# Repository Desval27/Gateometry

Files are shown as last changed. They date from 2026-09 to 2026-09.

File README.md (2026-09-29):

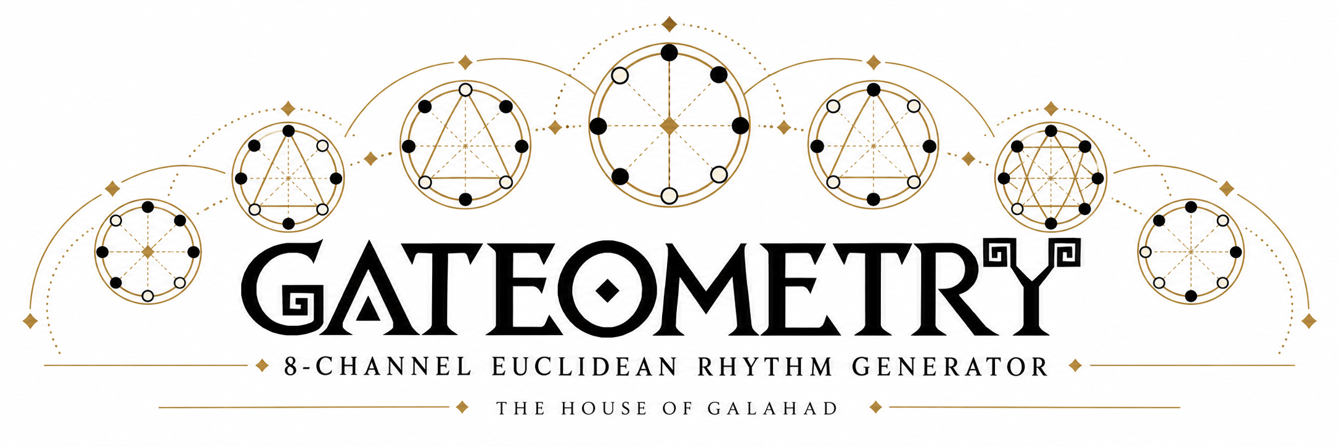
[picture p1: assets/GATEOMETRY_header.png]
Gateometry Header


# Gateometry

Eight-channel Euclidean rhythm generator for a **classic Arduino Nano, ATmega328P,
16 MHz / 5 V**, using a **128×64 SSD1306 I2C OLED** and Adafruit GFX. This does not
target the Nano Every, Nano ESP32, or a SH1106 display.

## Resources

!Untested!

- [PCB](hardware/README.md)
- [Panel](panel/README.md)

## Build and upload

```sh
pio run
pio run -t upload
```

The existing `nanoatmega328` environment is retained. It uses the old Nano
bootloader setting. For a newer bootloader, change the `board` setting to
`nanoatmega328new`; the environment name can stay unchanged. If necessary set
`upload_port` in `platformio.ini`. PlatformIO installs the Adafruit dependencies.

The sketch starts **stopped**, using the internal clock at **120 BPM**, with
**4 steps per beat** (sixteenth notes). All channels start with **N=16, K=4,
rotation=0, duty=50%**. Settings are RAM-only and return to defaults at power-up.

## Controls and display

- **Run/Stop button:** stop immediately clears all channel gates after button
  debounce. Starting resets every channel and plays slot zero on the next clock
  rising edge. The clock itself keeps running and remains available at Clock Out.
- **Overview:** rotate the encoder to select the header or one of eight channels;
  click to open the selected editor. The header opens global clock settings.
- **Inside either editor:** turn to change the highlighted parameter; click to
  select the next parameter. Hold for 600 ms to return to the overview.
- **Global editor:** choose Internal/External, BPM (20–300), and steps per beat
  (1, 2, 4, or 8). For source selection, clockwise selects External and
  counterclockwise selects Internal. BPM and steps/beat apply to the internal
  clock and the initial external gate-length estimate.
- **Channel editor:** N=1–32, K=0–N, signed rotation=−(N−1)…+(N−1), duty=1–99%.
  Reducing N clamps K and rotation to valid values. Changing a channel parameter
  clears its gate and restarts that channel at slot zero on the next clock;
  the other channels retain their position.
- **Mute toggles:** closed to ground = muted; open = enabled. Muting clears the
  gate after switch debounce; the channel continues counting slots. Unmuting
  waits for the next eligible hit, so it does not create a partial pulse.

Each overview necklace shows every slot, filled hits, and a radial playhead.
Slot zero is at twelve o'clock; time and positive rotation run clockwise.
A diagonal slash marks a muted channel; a small square indicates its gate is
currently high. The selected channel gets a border. The detail page enlarges
its necklace. At 32 slots the small overview is necessarily dense; use the
larger editor to inspect individual slots. The OLED refreshes at about 15 fps,
so very short pulses may not appear in every frame; physical LEDs follow gates.

## Clock and gate behavior

One clock rising edge advances **one slot on every channel**. Each channel wraps
at its own N. For example, N=5 and N=7 realign after 35 clock edges. Euclidean
onsets are evenly distributed with the first unrotated hit at slot zero:
N=8/K=3 gives `10010010`. A positive rotation of one gives `01001001`.

Internal clock interval is `60000 / (BPM × stepsPerBeat)` milliseconds, with a
fractional accumulator to avoid cumulative integer-rounding drift. Clock Out
and the clock LED use approximately 50% duty, and operate even while stopped.
The selected source is explicit; inserting a cable does not automatically
change sources. Changing source clears gates and resets channel positions.

External clock input uses D4's pin-change interrupt. Clock Out and its LED
follow **both edges** of the conditioned input, including while stopped. This
preserves incoming pulse width, with interrupt latency; it is a logic-level
copy, not an analog voltage copy. There is no clock multiplication or division
in external mode: feed a sixteenth-note clock if that is the desired slot rate.

External rising edges closer than 20 ms to the last accepted edge are ignored
by the sequencer (maximum accepted step rate 50 Hz), although Clock Out still
copies them. Use clean, debounced clock edges; this interval guard is not a
replacement for input conditioning. Period measurement supports 20–10,000 ms.
The first pulse, and the first after a gap longer than 10 seconds, uses the
internal BPM/steps setting to estimate its gate length. Following pulses use
the latest measured rising-to-rising interval. The header displays that interval
in milliseconds; `WAIT` appears after the longer of one second or three estimated
periods without a new accepted edge. It does not switch to the internal clock.
If the input stays high, Clock Out stays high as well.

Channel duty is a percentage of **one slot interval**, not the time between
filled slots. Width is quantized to milliseconds, with a minimum of one timer
tick and a maximum one tick shorter than the estimated interval. This leaves a
low gap between adjacent hits. When an external clock suddenly accelerates
before a previous gate has finished, that gate is lowered and retriggered on
the next 1 kHz timer tick. External widths depend on the previous interval,
so abrupt tempo changes cannot have a perfectly predicted duty cycle. If the
external clock disappears, active channel gates still expire normally.

## Nano pin allocation

The pin assignments are fixed in `src/main.cpp`. D2/D3, D4, D5/D6, and D10 use
AVR port/interrupt registers as well as Arduino pin constants; changing those
constants alone is insufficient to move these signals.

| Nano pin | Connection |
| --- | --- |
| D2 / INT0 | Encoder A, contact to ground, internal pull-up |
| D3 / INT1 | Encoder B, contact to ground, internal pull-up |
| D4 / PCINT20 | Conditioned external clock, active high, 0–5 V |
| D5 | Clock Out logic, through output buffer to jack |
| D6 | Clock LED anode through 2.2–4.7 kΩ; cathode to ground |
| D7 | 74HC165 SH/LD (active-low parallel load) |
| D8 | 74HC165 CLK |
| D9 | 74HC165 QH (non-inverted serial output) |
| D10 | 74HC595 RCLK (output latch) |
| D11 / MOSI | 74HC595 SER (serial data) |
| D13 / SCK | 74HC595 SRCLK (shift clock) |
| A0 | Encoder push switch to ground, internal pull-up |
| A1 | 74HC595 OE, with external 10 kΩ pull-up to +5 V |
| A2 | Run/Stop push switch to ground, internal pull-up |
| A4 / SDA | OLED SDA |
| A5 / SCL | OLED SCL |
| D0/D1, D12, A3 | Spare |
| A6/A7 | Unused; analog input only on this Nano |

The encoder common terminal goes to ground. No encoder or button pin is shared
with a jack. Quadrature decoding runs on both encoder interrupts. Set
`EncoderDirection` to −1 if needed; set `EncoderTransitions` to 2 for an encoder
that produces two transitions per detent instead of four.

OLED address defaults to `0x3C`; change `OledAddress` to `0x3D` if necessary.
Use a module compatible with the Nano's 5 V I2C levels, or add appropriate
level translation. A bare SSD1306 panel is not a drop-in 5 V module. The sketch
assumes the module supplies its own reset circuit (no dedicated OLED reset pin).
Use suitable I2C pull-ups and short wiring for the 400 kHz bus.

## Shift registers and output stages

Use **one 74HC595** for the eight gate logic signals, and **one 74HC165** for
the eight mute switches. The 165 uses a separate clock so switch scanning cannot
interfere with interrupt-driven gate updates. Gate LEDs can follow the buffered
gate signals, so no additional LED shift register is necessary.

For the usual 16-pin packages, verify the chosen manufacturer's pinout:

| 74HC595 signal | IC pin | Wire to |
| --- | --- | --- |
| VCC / GND | 16 / 8 | +5 V / ground |
| SER / SRCLK / RCLK | 14 / 11 / 12 | Nano D11 / D13 / D10 |
| OE | 13 | Nano A1 and 10 kΩ pull-up to +5 V |
| SRCLR | 10 | +5 V |
| QA | 15 | Channel 1 buffer input |
| QB…QH | 1…7 | Channels 2…8 buffer inputs |
| QH' | 9 | Unconnected |

Add a 100 kΩ pull-down at each buffer input driven by QA…QH. OE is held high
through reset and bootloader activity; these pull-downs define a low while the
595 outputs are high impedance. The sketch latches zeros before enabling OE.

| 74HC165 signal | IC pin | Wire to |
| --- | --- | --- |
| VCC / GND | 16 / 8 | +5 V / ground |
| SH/LD / CLK / QH | 1 / 2 / 9 | Nano D7 / D8 / D9 |
| CLK INH | 15 | Ground |
| SER | 10 | Ground |
| A / B / C / D | 11 / 12 / 13 / 14 | Channel 1 / 2 / 3 / 4 mute switch |
| E / F / G / H | 3 / 4 / 5 / 6 | Channel 5 / 6 / 7 / 8 mute switch |
| Inverted QH | 7 | Unconnected |

Each A…H input needs its **own 10 kΩ pull-up to +5 V** and a toggle switch to
ground. There are no internal pull-ups in the 165. Place 100 nF decoupling
capacitors at both registers and every buffer IC.

A practical prototype output arrangement is two **74AHCT541 non-inverting
octal buffers**, powered from +5 V. One serves the eight gate outputs; one
channel of the second serves Clock Out. Tie both active-low enables on each
buffer to ground, tie unused inputs to ground, and leave unused outputs open.
Add a 100 kΩ pull-down on the Clock Out buffer input as well.

```text
595 QA..QH ----+--> 74AHCT541 input
              |
             100k
              |
             GND

buffer output ---- 1k ---- gate jack tip
       |
       +---- 4.7k ---- LED anode; LED cathode to GND

Nano D5 --> buffered identically --> clock jack tip
jack sleeves ---------------------> common GND
```

This provides nominal 0/+5 V gates for modules that accept 5 V logic gates.
The series resistor limits short-circuit current and isolates cable loading;
keep per-pin and total package current within the buffer datasheet ratings.
Take the LED branch before the jack's series resistor. The clock LED already
has its own Nano D6 drive. The 595 only drives buffer inputs in this arrangement.
This is a prototype interface suggestion, not a fully protected Eurorack output
circuit: patching an output against an external voltage requires suitable
additional protection, and modules requiring higher gates need another driver.

**Do not connect a raw Eurorack clock jack directly to D4.** A practical
through-hole prototype input stage uses two gates of a **74HCT14 Schmitt-trigger
inverter**, powered from +5 V, and two **Vishay BAT85S Schottky clamp diodes**:

```text
clock jack tip ----+---- 22k ----+---- 74HCT14 ---- 74HCT14 ---- Nano D4
                  |            |      gate 1      gate 2
                 100k          +---- upper clamp to +5 V
                  |            +---- lower clamp to GND
                 GND

jack sleeve ------------------------------------------------ common GND
```

Connect both clamps at the protected node **after the 22 kΩ resistor**, close
to the first gate's input:

| Clamp diode | Anode | Cathode (banded end) |
| --- | --- | --- |
| Upper BAT85S | Protected input node | +5 V |
| Lower BAT85S | GND | Protected input node |

The 100 kΩ jack-to-ground pull-down defines the unplugged state. The 22 kΩ
series resistor limits current when an input goes below ground or above +5 V;
the diodes clamp the protected node near those rails. With approximately 0.3 V
diode drops, a +12 V input produces about 0.30 mA through the upper clamp, and
a −12 V input produces about 0.53 mA through the lower clamp.

The first gate's hysteresis cleans up slow or noisy transitions. The second
gate restores polarity, giving D4 clean, non-inverted 0–5 V logic that idles
low when unplugged. This matters because Clock Out follows both input edges.
The **74HCT14** has lower, TTL-compatible input thresholds than the 74HC14,
giving more margin for 3.3 V clocks while accepting 5 V clocks through the same
network. See the [74HC14/74HCT14 datasheet](https://assets.nexperia.com/documents/data-sheet/74HC_HCT14.pdf).
Place a **100 nF bypass capacitor** directly between the IC's supply pins;
tie unused gate inputs to ground and leave unused outputs unconnected.

The [Vishay BAT85S](https://www.vishay.com/docs/85513/bat85s.pdf) is an axial
**DO-35 through-hole** diode despite its “S” suffix; **BAT85S-TAP** is one
ordering code. It is rated for 30 V reverse voltage and 200 mA forward current,
with a maximum forward drop of 0.32 V at 1 mA at 25°C.

This is a starting circuit for a **powered prototype**, not a fully qualified
Eurorack input. Verify thresholds, clamp voltages and clean edges over the
intended input-voltage and temperature range. The upper clamp injects current
into the +5 V rail: the powered circuit must absorb that current without raising
the rail, and an external clock can partially power the module when it is off.
Powered-off patch protection needs additional circuitry. This analog front end
is separate from the sketch.

Supply the Nano, registers and buffers from a regulated +5 V rail with common
signal ground. A Eurorack +12 V rail must be regulated for these logic parts;
use proper reverse-polarity protection and decoupling at the module power input.
Plan USB/power isolation if the Nano will remain connected to USB while rack
power is present.

## Implementation and validation

- `include/RhythmEngine.h`: portable Euclidean pattern and clock/gate engine.
- `src/main.cpp`: Nano interrupts, shift registers, debounced controls, OLED UI.
- `test/test_engine.cpp`: host-side behavioral regression tests.

Timer1 runs at 1 kHz, owns gate expiration and internal clock generation, and
uses hardware SPI to latch the gate byte. External edges advance directly from
a pin-change ISR. Foreground changes and snapshots use short atomic blocks;
Wire/display operations never occur in interrupts. Timer0 remains available
for Arduino timekeeping. Do not add Servo/Timer1 code or another SPI owner
without redesigning this allocation. The onboard D13 LED will flicker with SPI
traffic; use the separate D6 clock LED on the panel.

An absent OLED leaves clock/gates and physical controls operational with the
default settings. A Wire timeout disables further display refreshes until
reset. Clock/gate interrupts continue during display transfers and timeouts.

Verified with PlatformIO Atmel AVR 5.3.0, Adafruit GFX 1.12.6, and Adafruit
SSD1306 2.5.17: **19,004 bytes flash; 546 bytes static RAM**. SSD1306 allocates
another **1,024 bytes at runtime**, which PlatformIO's RAM summary does not
include. That leaves about **478 bytes before heap bookkeeping and stack**.
Avoid adding `String`, large local arrays, or large libraries without reviewing
memory usage. Stack margin and ISR latency still need measurement on hardware.

Run the portable tests on a host with GCC:

```sh
g++ -std=c++11 -Wall -Wextra -Werror -pedantic \
    -fsanitize=address,undefined -Iinclude test/test_engine.cpp \
    -o /tmp/gateometry-test
/tmp/gateometry-test
```

The tests check every supported N/K/rotation combination, equal-spacing gaps,
clock counts at several BPM/subdivision extremes, gate-width bounds, run/stop,
independent channel lengths/duties, mute/unmute, external period estimation,
sudden tempo changes/retriggering, slow clocks, clock loss, and timer rollover.
The firmware builds and these tests pass. **Physical hardware has not been
exercised**. Before connecting other modules, verify output polarity/levels,
channel ordering, boot-time silence, encoder detents, input conditioning, and
clock/gate timing on a scope, including during OLED updates.

## References

- [Arduino Nano specifications](https://store.arduino.cc/arduino-nano)
- [ATmega328P datasheet: interrupt and timer registers](https://docs.arduino.cc/resources/datasheets/ATmega328P-datasheet.pdf)
- [PlatformIO Nano configuration](https://docs.platformio.org/en/latest/boards/atmelavr/nanoatmega328.html)
- [Adafruit SSD1306 implementation and framebuffer allocation](https://github.com/adafruit/Adafruit_SSD1306/blob/master/Adafruit_SSD1306.cpp)
- [TI 74HC595 datasheet](https://www.ti.com/lit/ds/symlink/sn74hc595.pdf)
- [TI 74HC165 datasheet and pinout](https://www.ti.com/product/SN74HC165)
- [TI 74AHCT541 buffer specifications](https://www.ti.com/product/SN74AHCT541)

## ⚠️ Disclaimer⚠️

This project is provided **"as is"**, without warranty of any kind, express or implied,
including but not limited to the warranties of merchantability, fitness for a
particular purpose, and noninfringement.

This is a DIY electronics project intended for educational and experimental use.
Use at your own risk.

The author assumes **no responsibility or liability** for any damage, injury, or loss
resulting from the use or misuse of this design, including but not limited to:

* Damage to connected equipment (Eurorack modules, power supplies, computers, etc.)
* Incorrect assembly or wiring
* Use with incompatible voltages or signal levels
* Personal injury

### Electrical Safety

This project may interface with:

* ±12V & +5V Power rails
* AC Mains Power (Lethal Risk)
* External control voltages (CV)
* Digital and analog circuitry

Improper handling may result in damage or unsafe conditions.

You are responsible for:

* Verifying all connections before powering the system
* Ensuring correct polarity of power connections
* Confirming voltage ranges and signal compatibility
* Using appropriate protection circuits where necessary

### No Guarantees

Schematics, PCB layouts, and code are provided for reference only.
They may contain errors, omissions, or design flaws.

**Always review and validate the design before building or using it.**

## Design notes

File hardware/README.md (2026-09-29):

# GATEOMETRY PCB

!Untested!

**Gateometry** is an eight-channel **Euclidean** rhythm generator for **Eurorack** modular synthesizers, built around an **Arduino Nano**. It generates programmable rhythmic gate patterns using the Euclidean algorithm, with independently configurable steps, pulses, rotation, and muting for each channel. The PCB integrates external clock and reset inputs, clock output, eight gate outputs, a rotary encoder for menu navigation, an OLED display, and dedicated run/stop and mute controls. Designed as a flexible platform for rhythmic experimentation, **Gateometry** combines algorithmic pattern generation with hands-on control and external clock synchronization.

## RESOURCES

- [Schematic](schematic.pdf)
- [Assembly](assembly.pdf)
- [Bill of Materials](bom.csv)
- [Interactive Bill of Materials](ibom.html)

## GERBER TO ORDER

- [Default](gerber_to_order/Gateometry_191.3x150.0mm_for_Default.zip)
- [Elecrow](gerber_to_order/Gateometry_191.3x150.0mm_for_Elecrow.zip)
- [FusionPCB](gerber_to_order/Gateometry_191.3x150.0mm_for_FusionPCB.zip)
- [JLCPCB](gerber_to_order/Gateometry_191.3x150.0mm_for_JLCPCB.zip)
- [PCBWay](gerber_to_order/Gateometry_191.3x150.0mm_for_PCBWay.zip)

## RENDERS

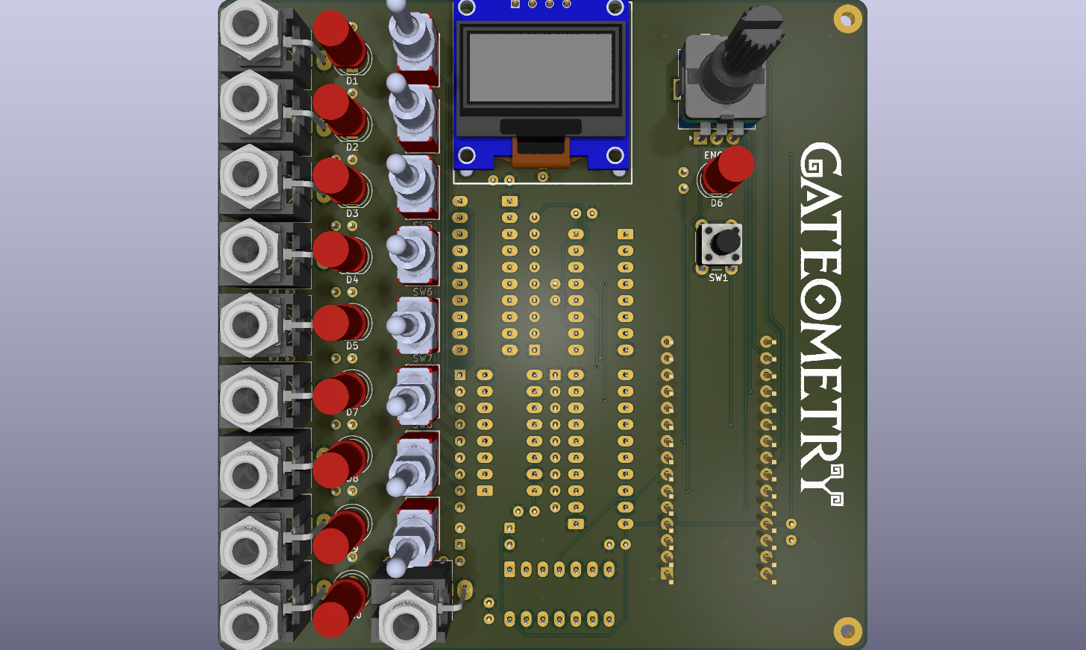
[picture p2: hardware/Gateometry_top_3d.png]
PCB Top 3D


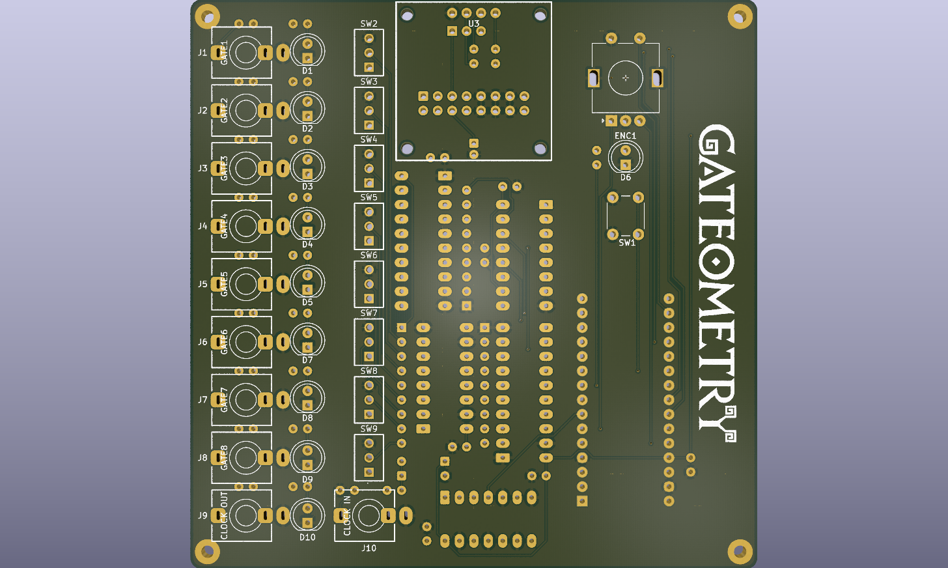
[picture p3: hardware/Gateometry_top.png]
PCB Top


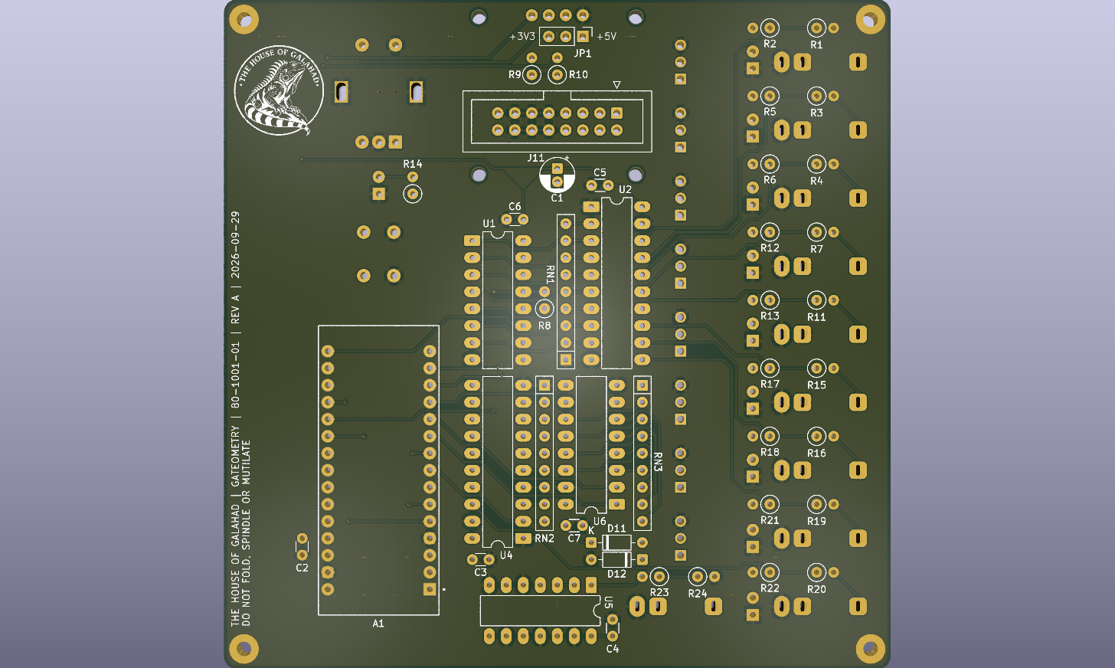
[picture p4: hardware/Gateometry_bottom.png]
PCB Bottom


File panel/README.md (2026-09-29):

# GATEOMETRY PANEL

!Untested!

The **Gateometry** front panel provides a compact (for a given value of compact), intuitive interface for the eight-channel **Euclidean** rhythm generator. It features an OLED display for pattern visualization and menu navigation, a rotary encoder with an integrated pushbutton for parameter selection and editing, and dedicated run/stop and mute controls with LED status indication. Eight individual gate output jacks provide connections to external **Eurorack** modules, while clock input, clock output, and reset connections allow integration with other sequencers and clock sources. The panel is designed to provide convenient access to **Gateometry**'s rhythmic capabilities while maintaining a clean, functional **Eurorack** layout.

## GERBER TO ORDER

- [Default](gerber_to_order/GateometryPanel_149.39x159.45mm_for_Default.zip)
- [Elecrow](gerber_to_order/GateometryPanel_149.39x159.45mm_for_Elecrow.zip)
- [FusionPCB](gerber_to_order/GateometryPanel_149.39x159.45mm_for_FusionPCB.zip)
- [JLCPCB](gerber_to_order/GateometryPanel_149.39x159.45mm_for_JLCPCB.zip)
- [PCBWay](gerber_to_order/GateometryPanel_149.39x159.45mm_for_PCBWay.zip)

## RENDERS

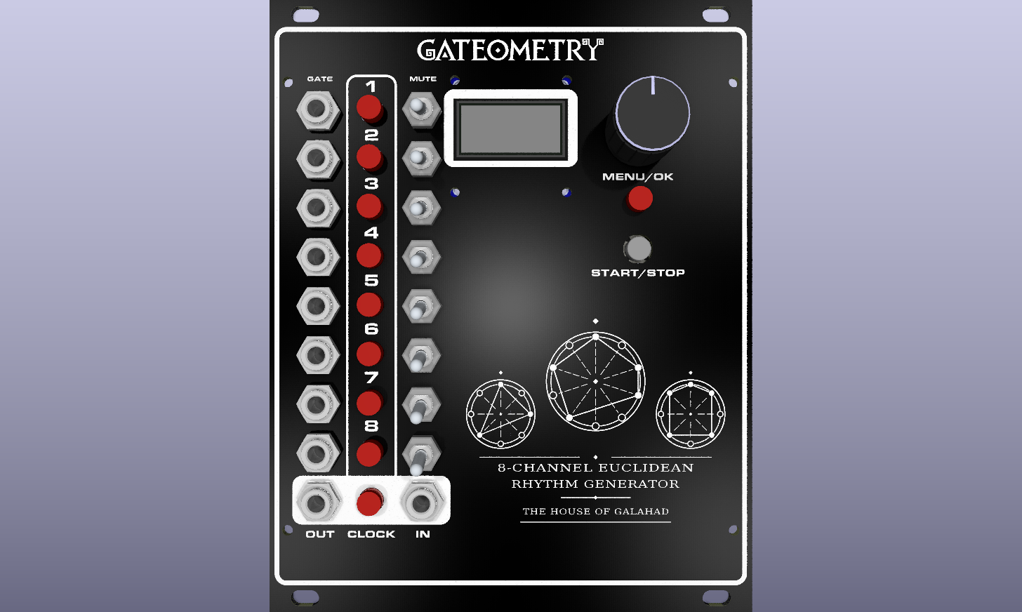
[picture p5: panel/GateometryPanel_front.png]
Panel Front


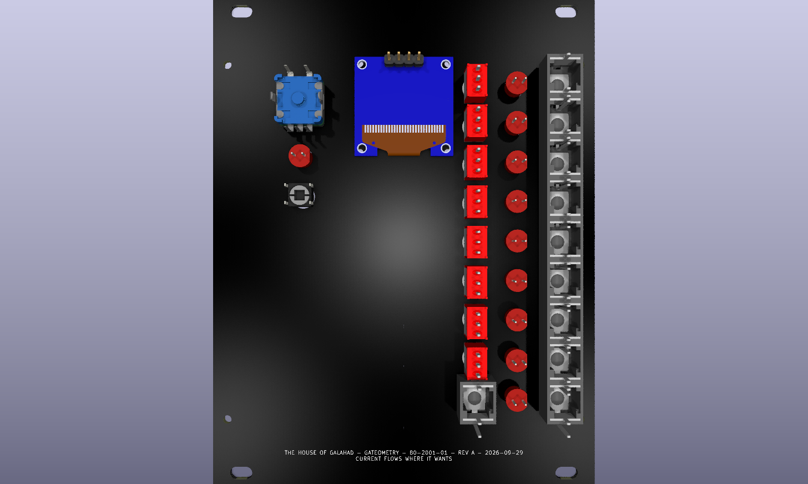
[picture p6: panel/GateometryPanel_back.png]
Panel Back


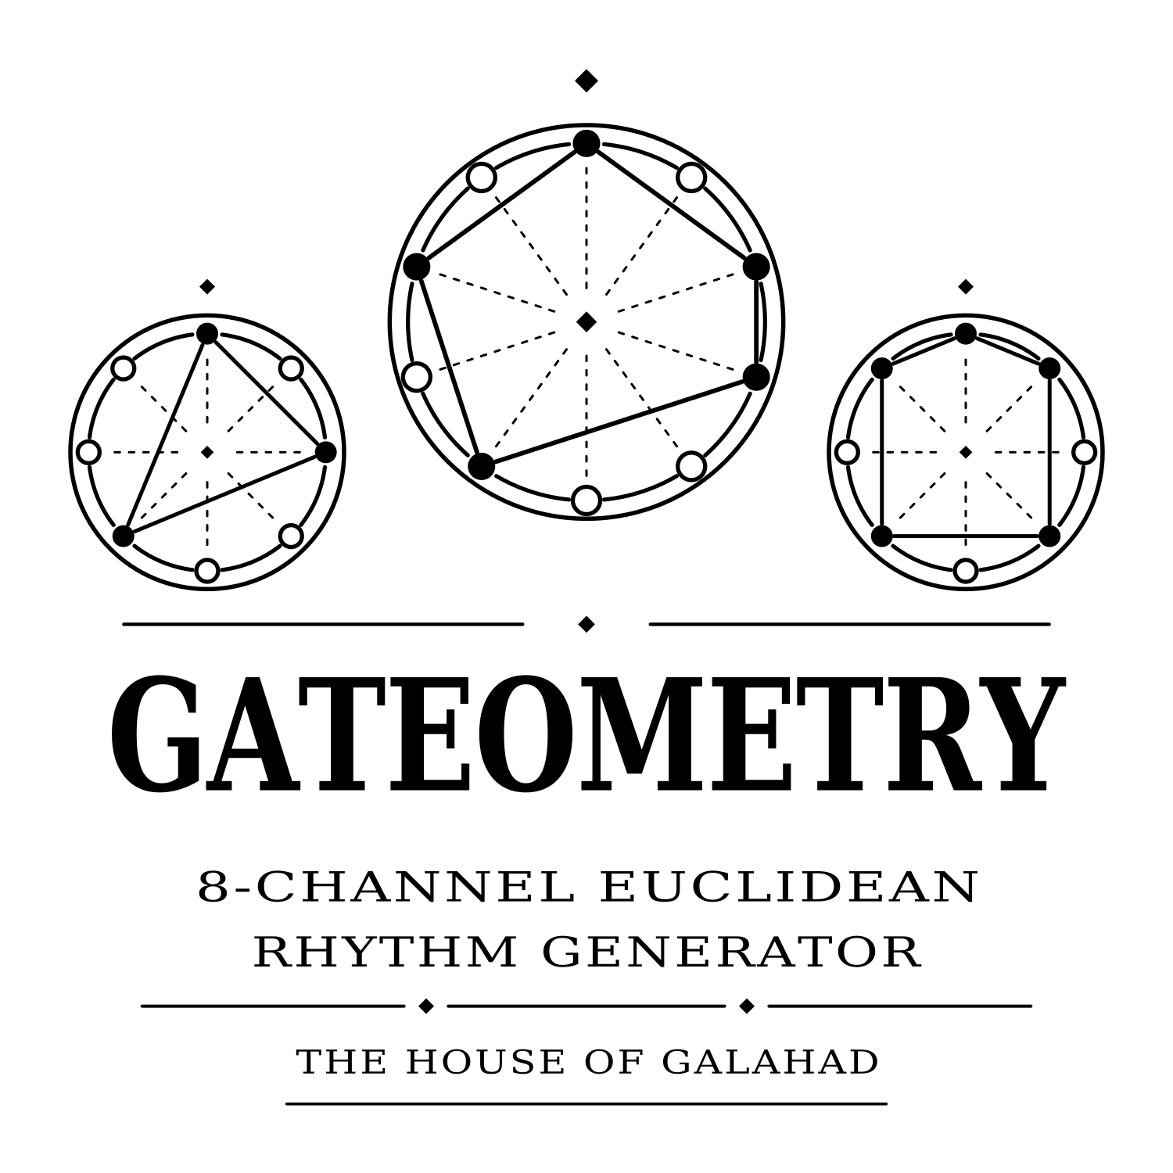
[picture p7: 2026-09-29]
assets/Gateometry_front_panel_3in_preview.png

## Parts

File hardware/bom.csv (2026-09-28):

Reference | Qty | Value | DNP | Exclude from BOM | Exclude from Board | Exclude from Simulation | Exclude from Position Files | Footprint | Datasheet
A1 | 1 | Arduino_Nano_v3.x |  |  |  |  | ${EXCLUDE_FROM_POS_FILES} | Desval27:MODULE_ARDUINO_NANO | http://www.mouser.com/pdfdocs/Gravitech_Arduino_Nano3_0.pdf
C1 | 1 | 47µ |  |  |  |  | ${EXCLUDE_FROM_POS_FILES} | Capacitor_THT:CP_Radial_D5.0mm_P2.00mm
C2,C3,C4,C5,C6,C7 | 6 | 100n |  |  |  |  | ${EXCLUDE_FROM_POS_FILES} | Capacitor_THT:C_Disc_D3.0mm_W1.6mm_P2.50mm
D1 | 1 | GATE1 LED |  |  |  |  | ${EXCLUDE_FROM_POS_FILES} | LED_THT:LED_D5.0mm_FlatTop
D2 | 1 | GATE2 LED |  |  |  |  | ${EXCLUDE_FROM_POS_FILES} | LED_THT:LED_D5.0mm_FlatTop
D3 | 1 | GATE3 LED |  |  |  |  | ${EXCLUDE_FROM_POS_FILES} | LED_THT:LED_D5.0mm_FlatTop
D4 | 1 | GATE4 LED |  |  |  |  | ${EXCLUDE_FROM_POS_FILES} | LED_THT:LED_D5.0mm_FlatTop
D5 | 1 | GATE5 LED |  |  |  |  | ${EXCLUDE_FROM_POS_FILES} | LED_THT:LED_D5.0mm_FlatTop
D6 | 1 | CLOCK LED |  |  |  |  | ${EXCLUDE_FROM_POS_FILES} | LED_THT:LED_D5.0mm_FlatTop
D7 | 1 | GATE6 LED |  |  |  |  | ${EXCLUDE_FROM_POS_FILES} | LED_THT:LED_D5.0mm_FlatTop
D8 | 1 | GATE7 LED |  |  |  |  | ${EXCLUDE_FROM_POS_FILES} | LED_THT:LED_D5.0mm_FlatTop
D9 | 1 | GATE8 LED |  |  |  |  | ${EXCLUDE_FROM_POS_FILES} | LED_THT:LED_D5.0mm_FlatTop
D10 | 1 | CLOCK OUT LED |  |  |  |  | ${EXCLUDE_FROM_POS_FILES} | LED_THT:LED_D5.0mm_FlatTop
D11,D12 | 2 | BAT85 |  |  |  |  | ${EXCLUDE_FROM_POS_FILES} | Diode_THT:D_DO-35_SOD27_P7.62mm_Horizontal | https://assets.nexperia.com/documents/data-sheet/BAT85.pdf
ENC1 | 1 | ROTARY ENCODER |  |  |  |  | ${EXCLUDE_FROM_POS_FILES} | Desval27:Rotary Encoder
J1 | 1 | GATE1 |  |  |  |  | ${EXCLUDE_FROM_POS_FILES} | Desval27:Jack_3.5mm_QingPu_WQP-PJ398SM_Vertical
J2 | 1 | GATE2 |  |  |  |  | ${EXCLUDE_FROM_POS_FILES} | Desval27:Jack_3.5mm_QingPu_WQP-PJ398SM_Vertical
J3 | 1 | GATE3 |  |  |  |  | ${EXCLUDE_FROM_POS_FILES} | Desval27:Jack_3.5mm_QingPu_WQP-PJ398SM_Vertical
J4 | 1 | GATE4 |  |  |  |  | ${EXCLUDE_FROM_POS_FILES} | Desval27:Jack_3.5mm_QingPu_WQP-PJ398SM_Vertical
J5 | 1 | GATE5 |  |  |  |  | ${EXCLUDE_FROM_POS_FILES} | Desval27:Jack_3.5mm_QingPu_WQP-PJ398SM_Vertical
J6 | 1 | GATE6 |  |  |  |  | ${EXCLUDE_FROM_POS_FILES} | Desval27:Jack_3.5mm_QingPu_WQP-PJ398SM_Vertical
J7 | 1 | GATE7 |  |  |  |  | ${EXCLUDE_FROM_POS_FILES} | Desval27:Jack_3.5mm_QingPu_WQP-PJ398SM_Vertical
J8 | 1 | GATE8 |  |  |  |  | ${EXCLUDE_FROM_POS_FILES} | Desval27:Jack_3.5mm_QingPu_WQP-PJ398SM_Vertical
J9 | 1 | CLOCK OUT |  |  |  |  | ${EXCLUDE_FROM_POS_FILES} | Desval27:Jack_3.5mm_QingPu_WQP-PJ398SM_Vertical
J10 | 1 | CLOCK IN |  |  |  |  | ${EXCLUDE_FROM_POS_FILES} | Desval27:Jack_3.5mm_QingPu_WQP-PJ398SM_Vertical
J11 | 1 | POWER |  |  |  |  | ${EXCLUDE_FROM_POS_FILES} | Connector_IDC:IDC-Header_2x08_P2.54mm_Vertical
R1,R3,R4,R7,R11,R15,R16,R19,R20 | 9 | 1k |  |  |  |  | ${EXCLUDE_FROM_POS_FILES} | Resistor_THT:R_Axial_DIN0207_L6.3mm_D2.5mm_P2.54mm_Vertical
R2,R5,R6,R12,R13,R17,R18,R21,R22 | 9 | 4k7 |  |  |  |  | ${EXCLUDE_FROM_POS_FILES} | Resistor_THT:R_Axial_DIN0207_L6.3mm_D2.5mm_P2.54mm_Vertical
R8,R9,R10 | 3 | 10k |  |  |  |  | ${EXCLUDE_FROM_POS_FILES} | Resistor_THT:R_Axial_DIN0207_L6.3mm_D2.5mm_P2.54mm_Vertical
R14 | 1 | 2k2 |  |  |  |  | ${EXCLUDE_FROM_POS_FILES} | Resistor_THT:R_Axial_DIN0207_L6.3mm_D2.5mm_P2.54mm_Vertical
R23 | 1 | 22k |  |  |  |  | ${EXCLUDE_FROM_POS_FILES} | Resistor_THT:R_Axial_DIN0207_L6.3mm_D2.5mm_P2.54mm_Vertical
R24 | 1 | 100k |  |  |  |  | ${EXCLUDE_FROM_POS_FILES} | Resistor_THT:R_Axial_DIN0207_L6.3mm_D2.5mm_P2.54mm_Vertical
RN1,RN2 | 2 | 100k |  |  |  |  | ${EXCLUDE_FROM_POS_FILES} | Resistor_THT:R_Array_SIP9 | http://www.vishay.com/docs/31509/csc.pdf
RN3 | 1 | 10k |  |  |  |  | ${EXCLUDE_FROM_POS_FILES} | Resistor_THT:R_Array_SIP9 | http://www.vishay.com/docs/31509/csc.pdf
SW1 | 1 | RUN/STOP |  |  |  |  | ${EXCLUDE_FROM_POS_FILES} | Button_Switch_THT:SW_PUSH_6mm_H8mm
SW2 | 1 | MUTE 1 |  |  |  |  | ${EXCLUDE_FROM_POS_FILES} | Desval27:2MS1T1B1M2QES
SW3 | 1 | MUTE 2 |  |  |  |  | ${EXCLUDE_FROM_POS_FILES} | Desval27:2MS1T1B1M2QES
SW4 | 1 | MUTE 3 |  |  |  |  | ${EXCLUDE_FROM_POS_FILES} | Desval27:2MS1T1B1M2QES
SW5 | 1 | MUTE 4 |  |  |  |  | ${EXCLUDE_FROM_POS_FILES} | Desval27:2MS1T1B1M2QES
SW6 | 1 | MUTE 5 |  |  |  |  | ${EXCLUDE_FROM_POS_FILES} | Desval27:2MS1T1B1M2QES
SW7 | 1 | MUTE 6 |  |  |  |  | ${EXCLUDE_FROM_POS_FILES} | Desval27:2MS1T1B1M2QES
SW8 | 1 | MUTE 7 |  |  |  |  | ${EXCLUDE_FROM_POS_FILES} | Desval27:2MS1T1B1M2QES
SW9 | 1 | MUTE 8 |  |  |  |  | ${EXCLUDE_FROM_POS_FILES} | Desval27:2MS1T1B1M2QES
U1 | 1 | 74HC595 |  |  |  |  | ${EXCLUDE_FROM_POS_FILES} | Package_DIP:DIP-16_W7.62mm_LongPads | http://www.ti.com/lit/ds/symlink/sn74hc595.pdf
U2,U4 | 2 | 74HCT541 |  |  |  |  | ${EXCLUDE_FROM_POS_FILES} | Package_DIP:DIP-20_W7.62mm_LongPads | http://www.ti.com/lit/gpn/sn74HCT541
U3 | 1 | 0.96 Inch OLED I2C Display Module |  |  |  |  | ${EXCLUDE_FROM_POS_FILES} | Desval27:0.96 Inch OLED I2C Display Module | https://atta.szlcsc.com/upload/public/pdf/source/20240311/1DABDC0F0F4D195A378941843D39FB20.pdf
U5 | 1 | 74HCT14 |  |  |  |  | ${EXCLUDE_FROM_POS_FILES} | Package_DIP:DIP-14_W7.62mm_LongPads | http://www.ti.com/lit/gpn/sn74HC14
U6 | 1 | 74HC165 |  |  |  |  | ${EXCLUDE_FROM_POS_FILES} | Package_DIP:DIP-16_W7.62mm_LongPads | https://assets.nexperia.com/documents/data-sheet/74HC_HCT165.pdf

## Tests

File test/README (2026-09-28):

Portable engine tests (no board required):

  g++ -std=c++11 -Wall -Wextra -Werror -pedantic \
      -fsanitize=address,undefined -Iinclude test/test_engine.cpp \
      -o /tmp/gateometry-test
  /tmp/gateometry-test

Run from the project root. These standalone tests use standard assert rather
than the PlatformIO device test runner. See ../README.md for hardware checks.

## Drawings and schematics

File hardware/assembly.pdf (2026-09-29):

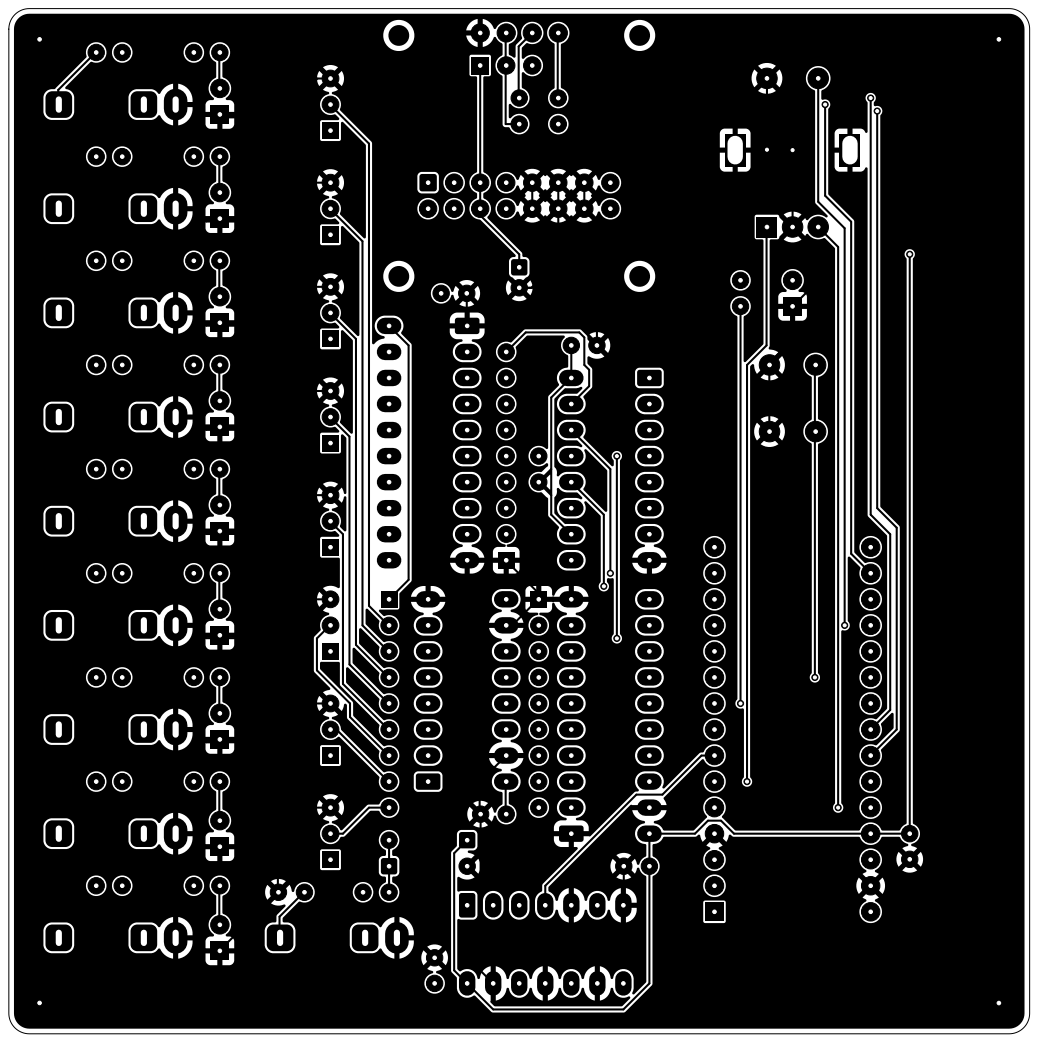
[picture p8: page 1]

DO NOT FOLD, SPINDLE OR MUTILATE
THE HOUSE OF GALAHAD
Sheet:
File: Gateometry.kicad_pcb
Title: GATEOMETRY

Size: A4 | Rev: A
KiCad E.D.A. 10.0.5 | Id: 1/8

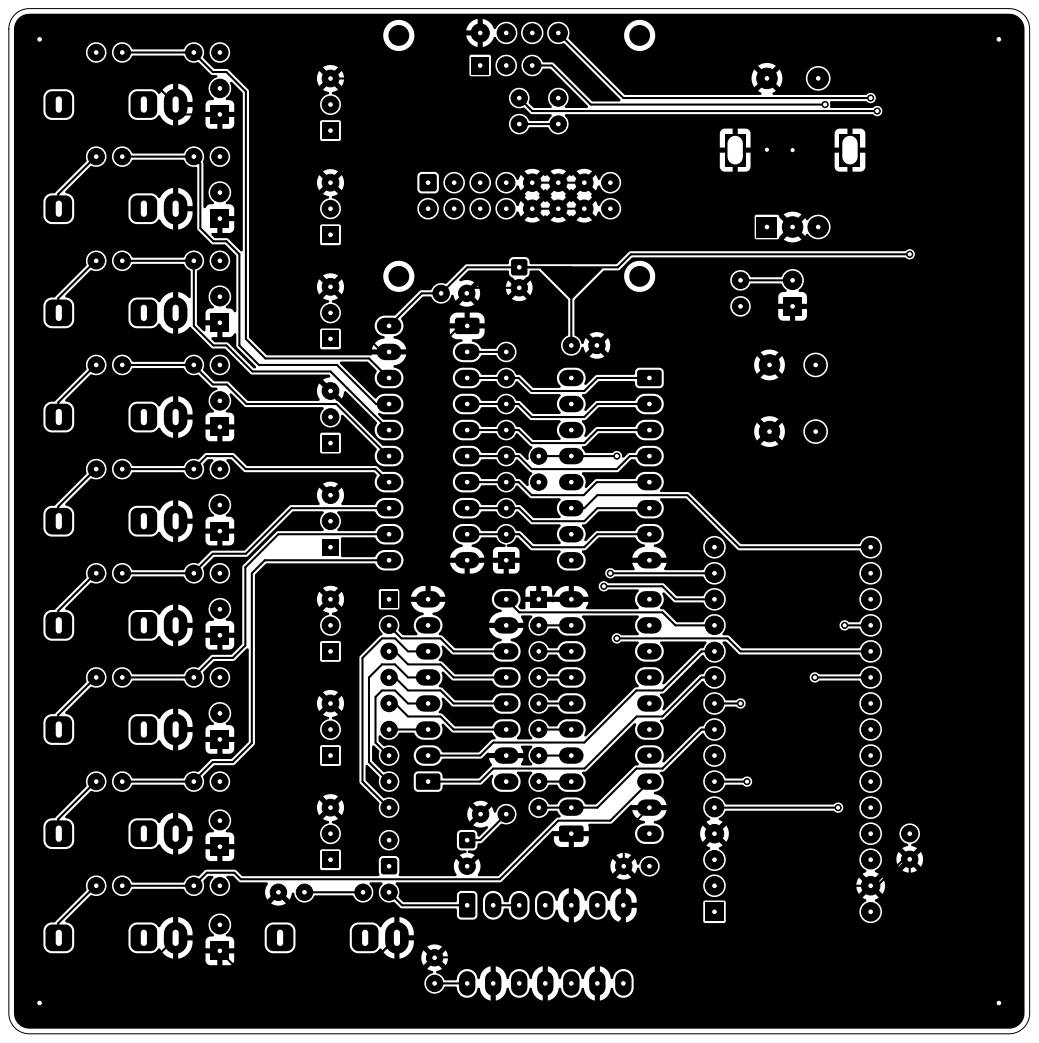
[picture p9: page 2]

DO NOT FOLD, SPINDLE OR MUTILATE
THE HOUSE OF GALAHAD
Sheet:
File: Gateometry.kicad_pcb
Title: GATEOMETRY

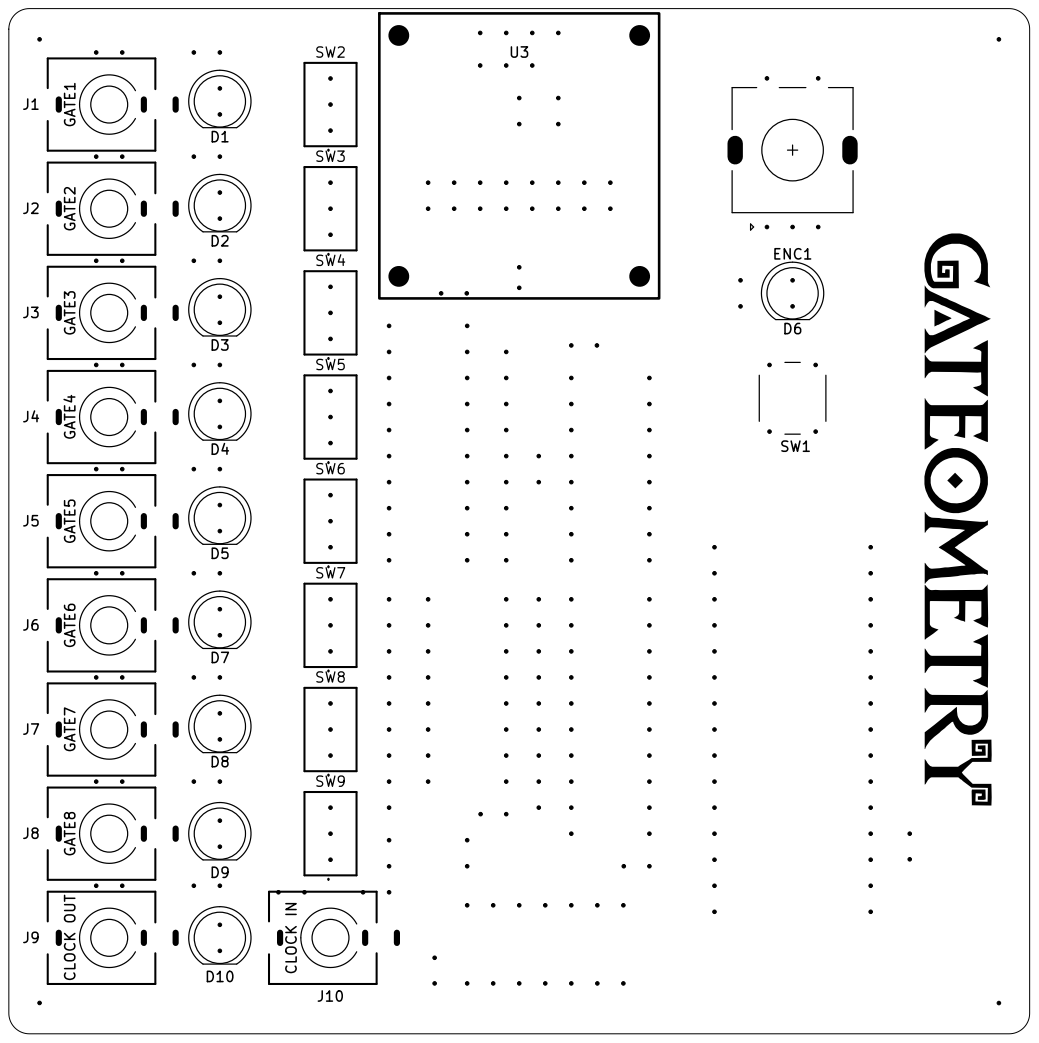
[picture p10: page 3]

DO NOT FOLD, SPINDLE OR MUTILATE
THE HOUSE OF GALAHAD
Sheet:
File: Gateometry.kicad_pcb
Title: GATEOMETRY

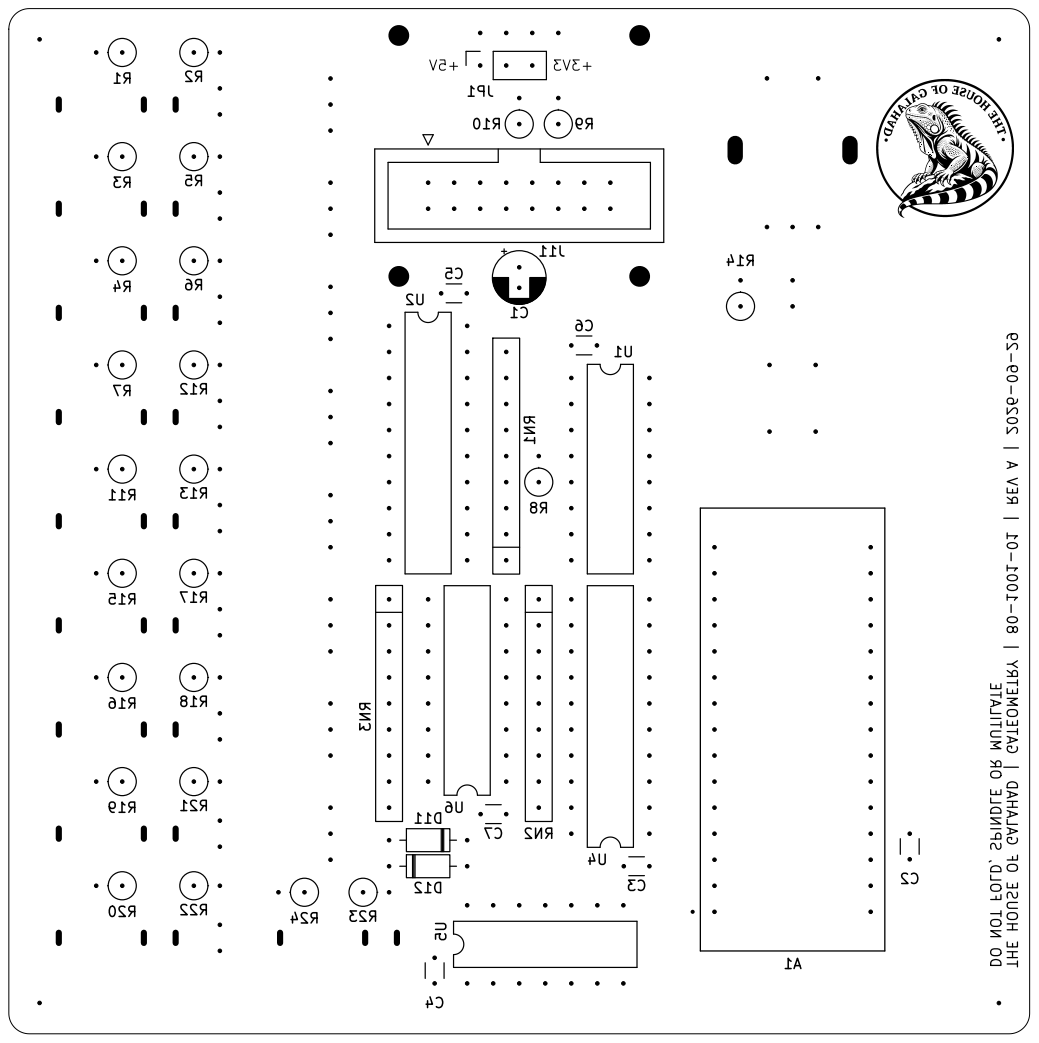
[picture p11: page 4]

DO NOT FOLD, SPINDLE OR MUTILATE
THE HOUSE OF GALAHAD
Sheet:
File: Gateometry.kicad_pcb
Title: GATEOMETRY

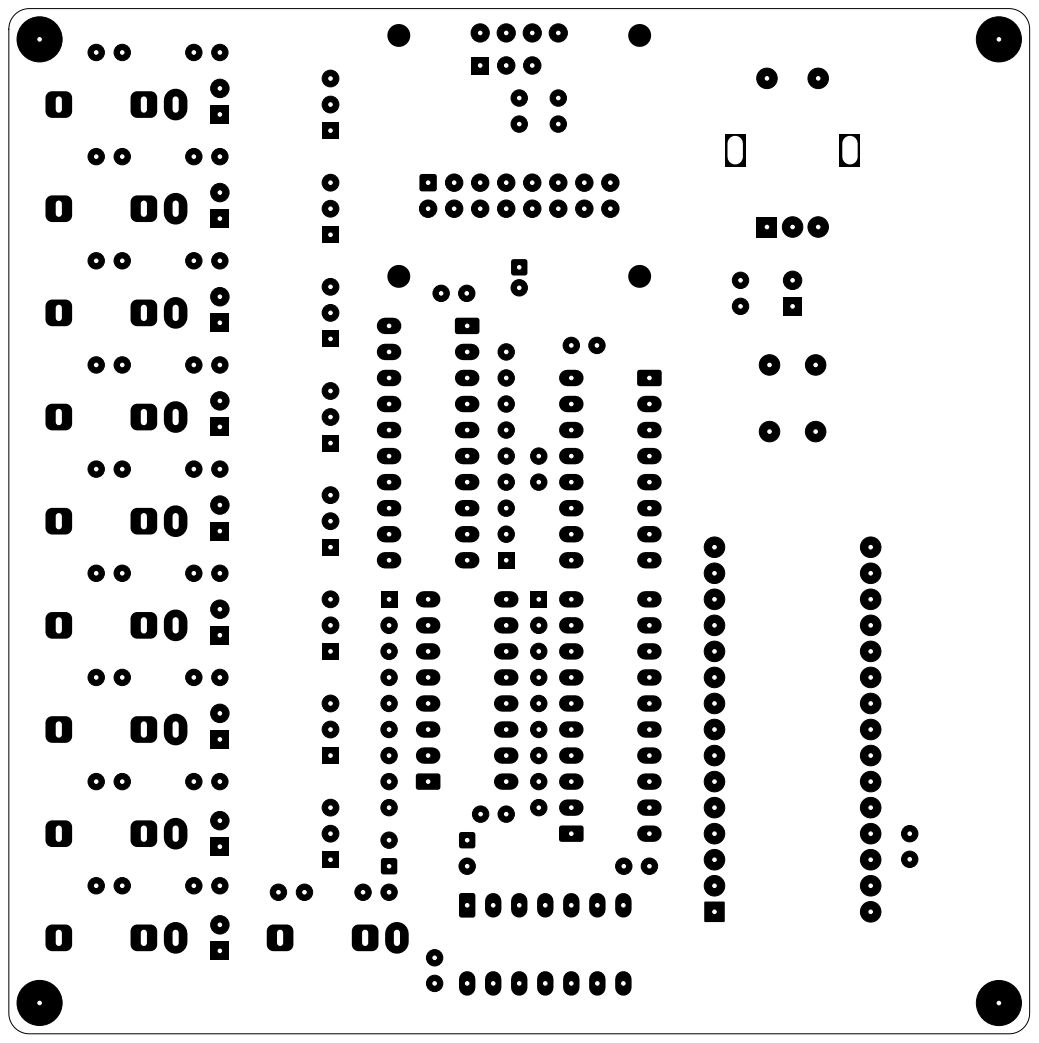
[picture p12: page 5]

DO NOT FOLD, SPINDLE OR MUTILATE
THE HOUSE OF GALAHAD
Sheet:
File: Gateometry.kicad_pcb
Title: GATEOMETRY

DO NOT FOLD, SPINDLE OR MUTILATE
THE HOUSE OF GALAHAD
Sheet:
File: Gateometry.kicad_pcb
Title: GATEOMETRY

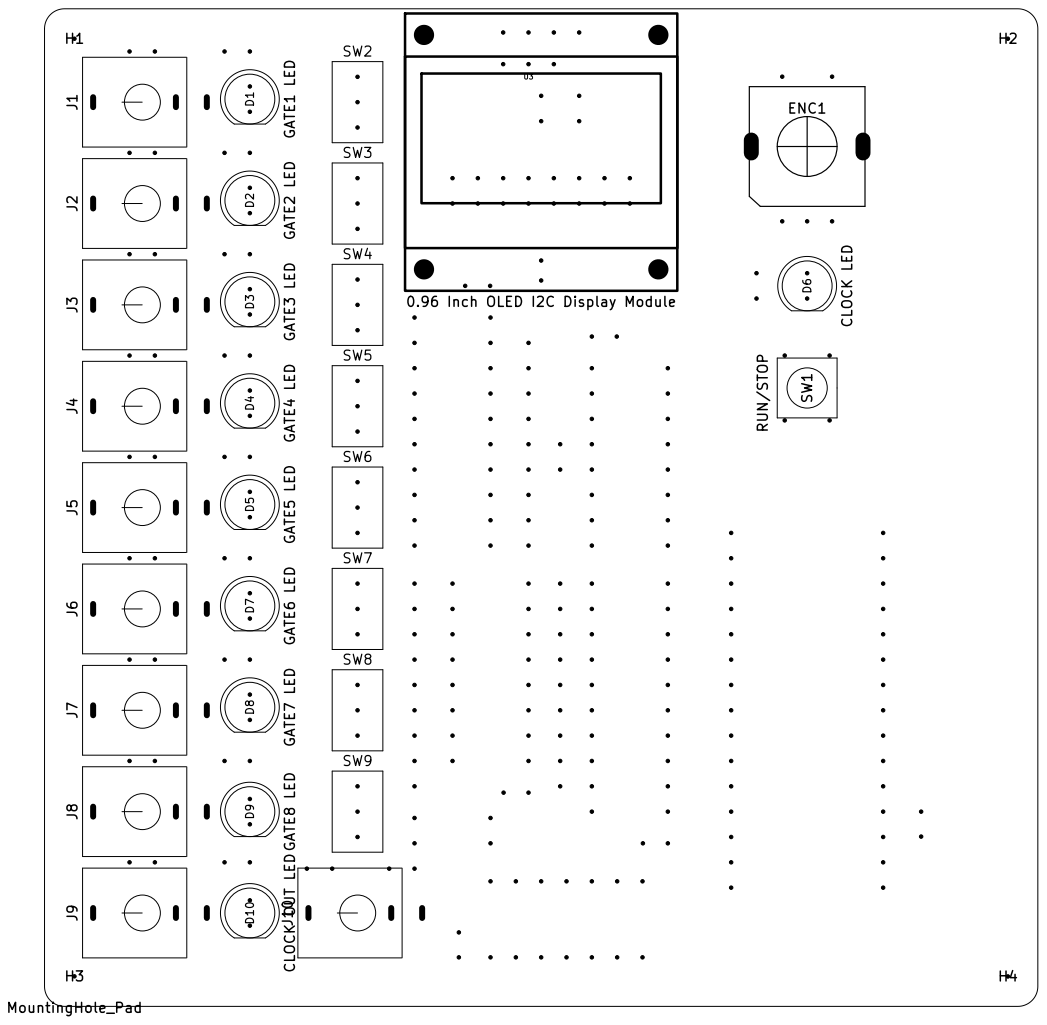
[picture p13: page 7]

0.96 Inch OLED I2C Display Module

DO NOT FOLD, SPINDLE OR MUTILATE
THE HOUSE OF GALAHAD
Sheet:
File: Gateometry.kicad_pcb
Title: GATEOMETRY

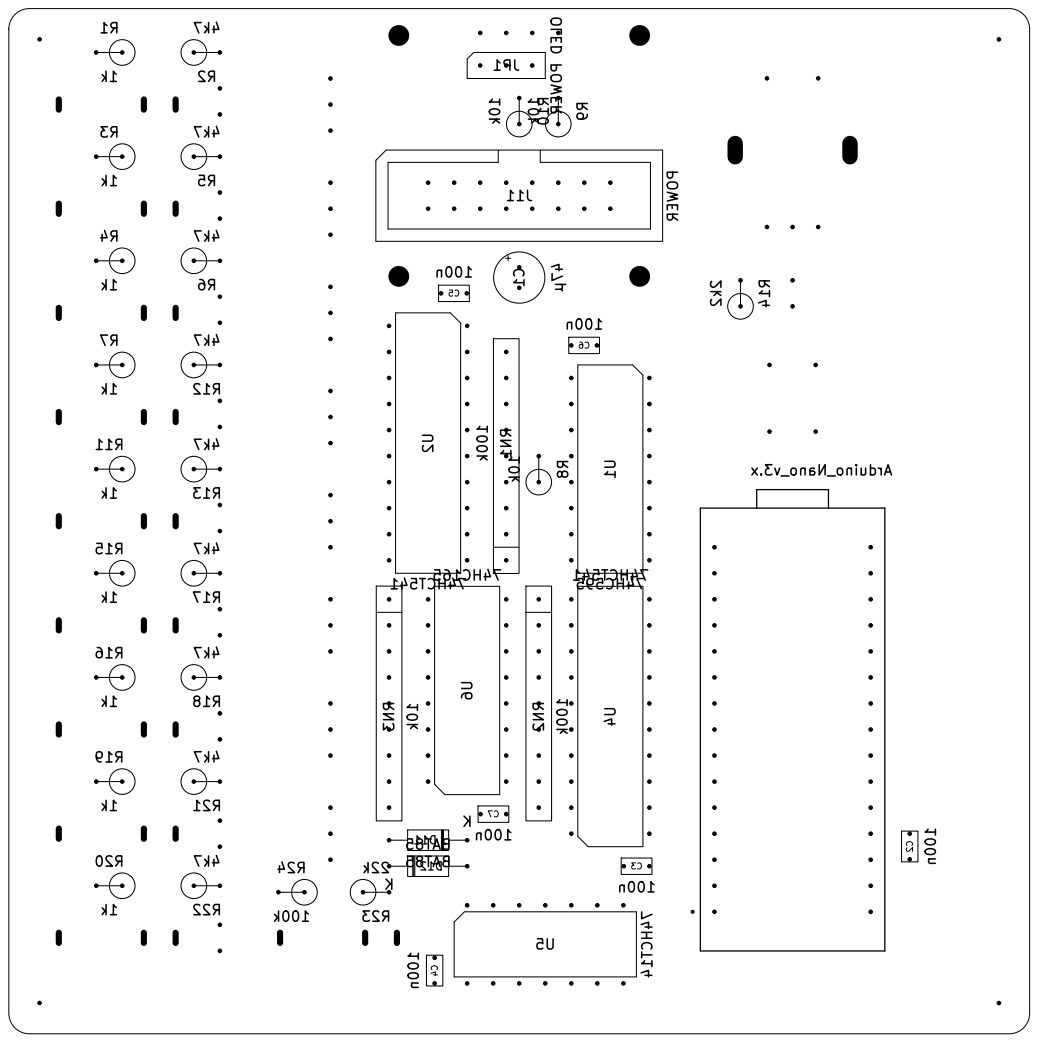
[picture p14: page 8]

DO NOT FOLD, SPINDLE OR MUTILATE
THE HOUSE OF GALAHAD
Sheet:
File: Gateometry.kicad_pcb
Title: GATEOMETRY

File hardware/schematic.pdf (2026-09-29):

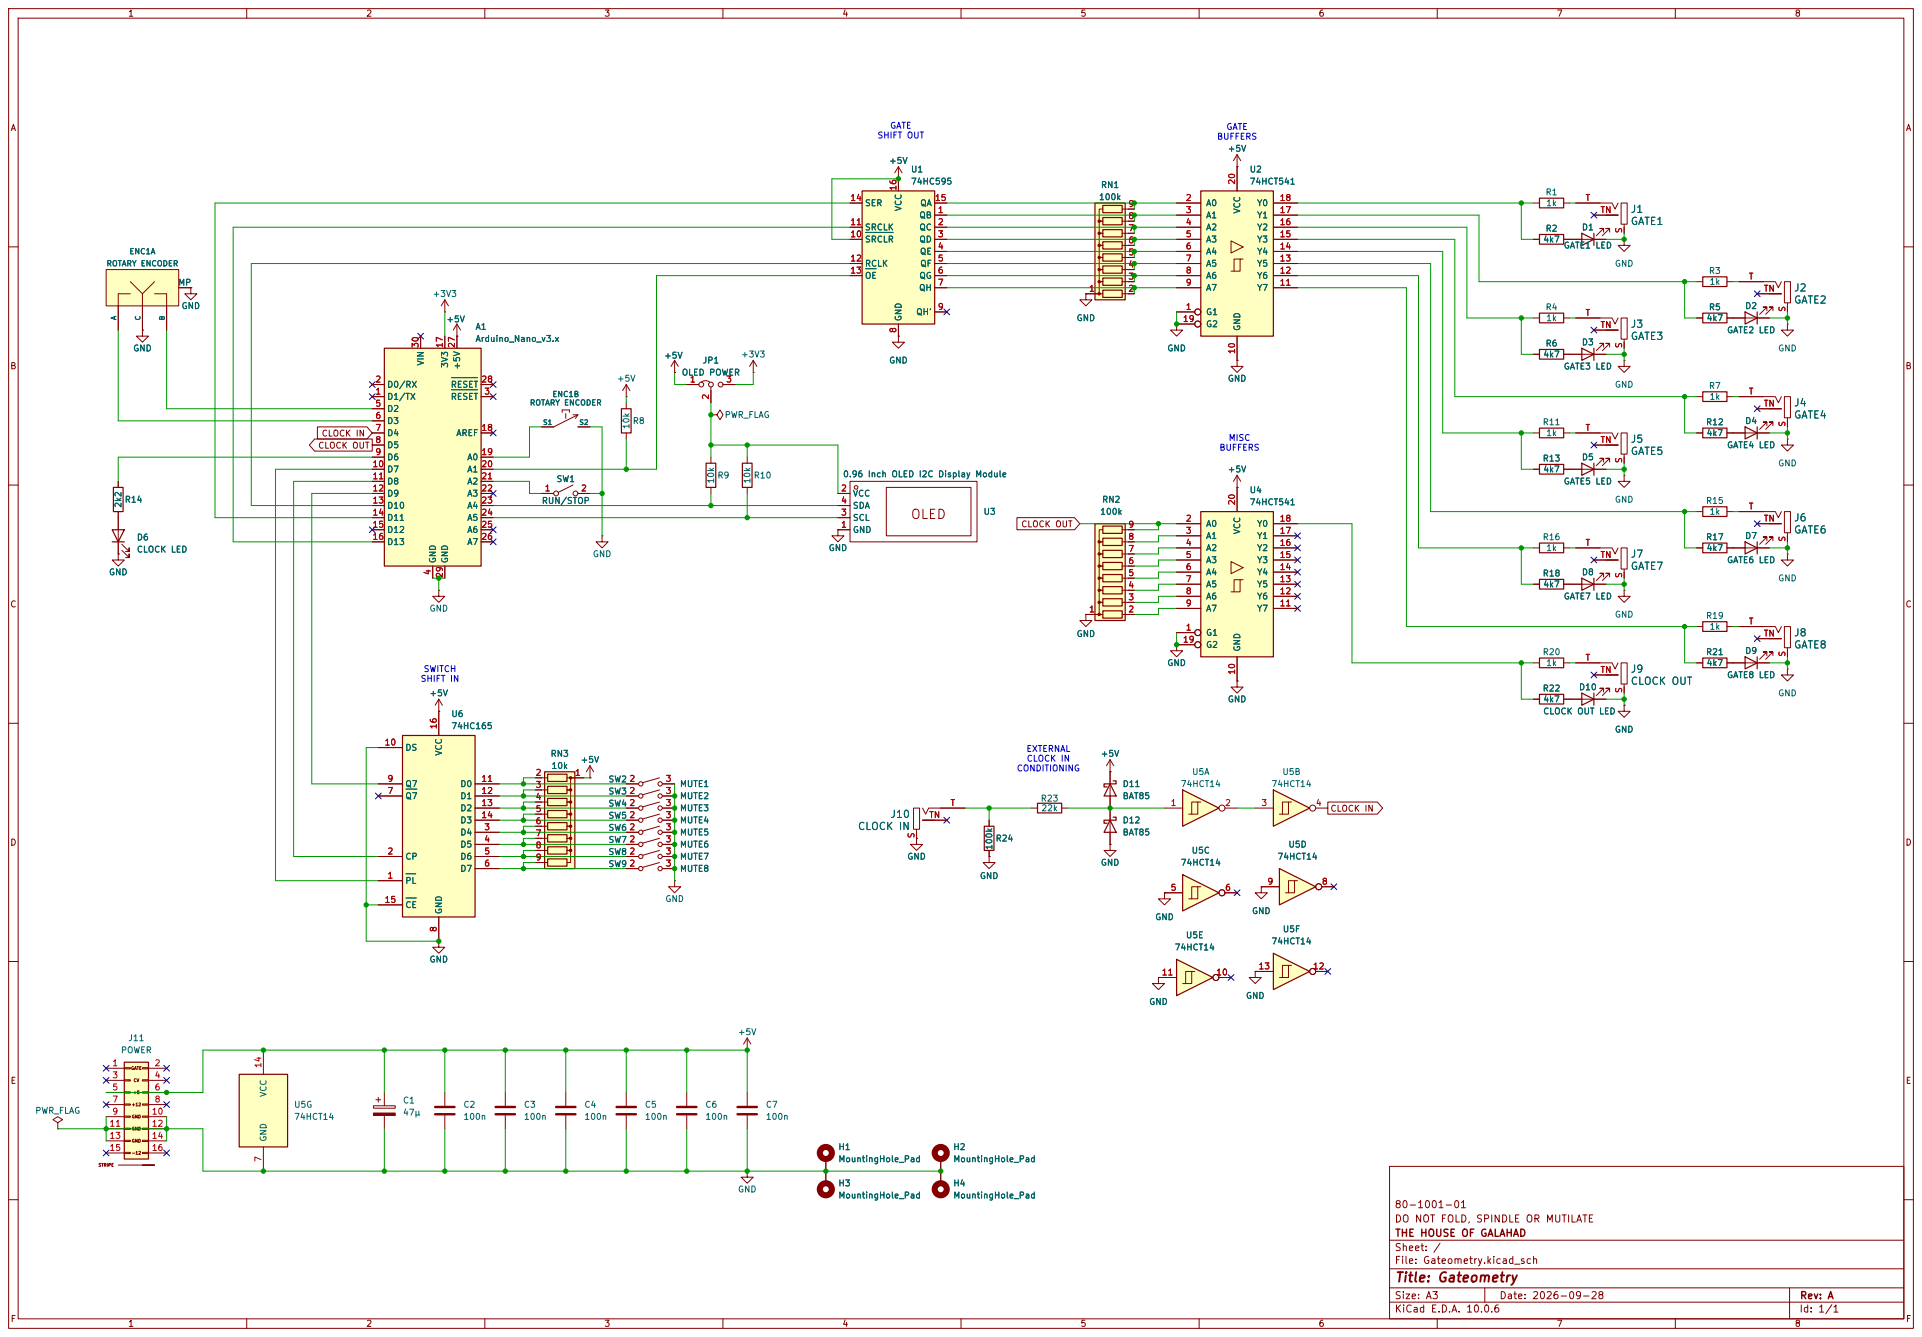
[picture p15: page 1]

SRCLR 10 SRCLK 11 RCLK 12 OE 13 | | 100k 1 | 2 7 7 6 6 | A3 5

5 5 | A4 6
4 4 | A5 7

0.96 Inch OLED I2C Display Module GND 1
VCC 2
SCL 3
GND 1

DO NOT FOLD, SPINDLE OR MUTILATE
THE HOUSE OF GALAHAD
Sheet: /
File: Gateometry.kicad_sch
Title: Gateometry

Size: A3 | Rev: A | F Date: 2026-09-28
KiCad E.D.A. 10.0.6 | Id: 1/1

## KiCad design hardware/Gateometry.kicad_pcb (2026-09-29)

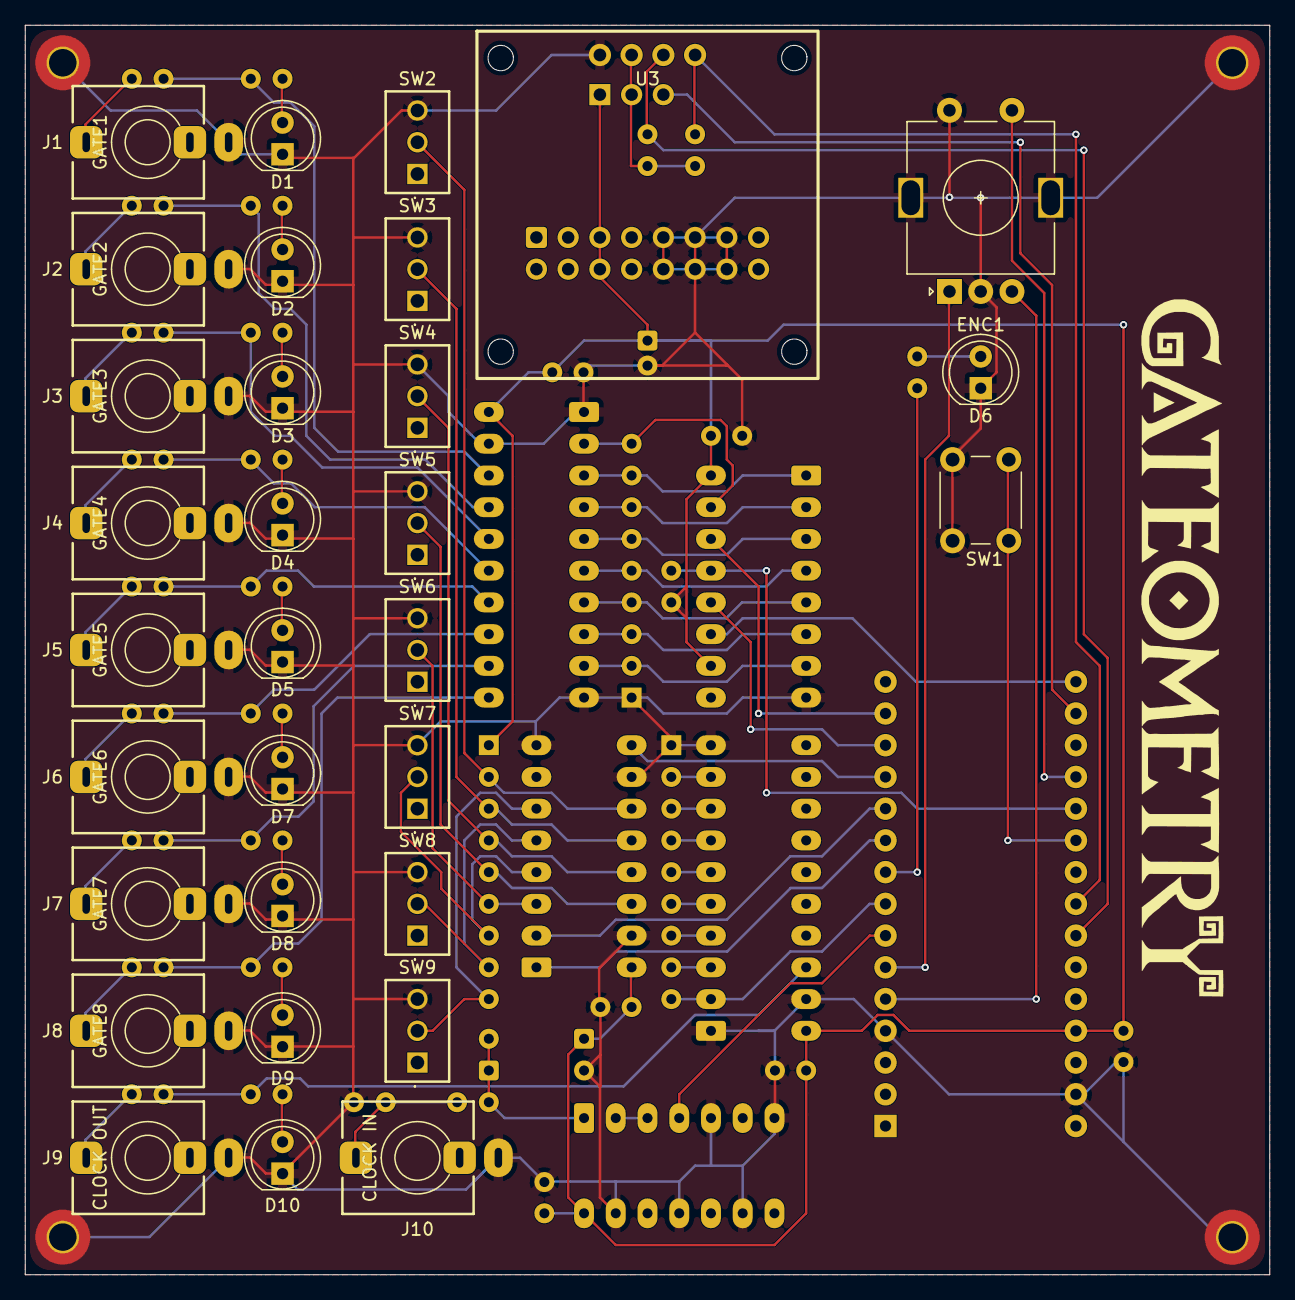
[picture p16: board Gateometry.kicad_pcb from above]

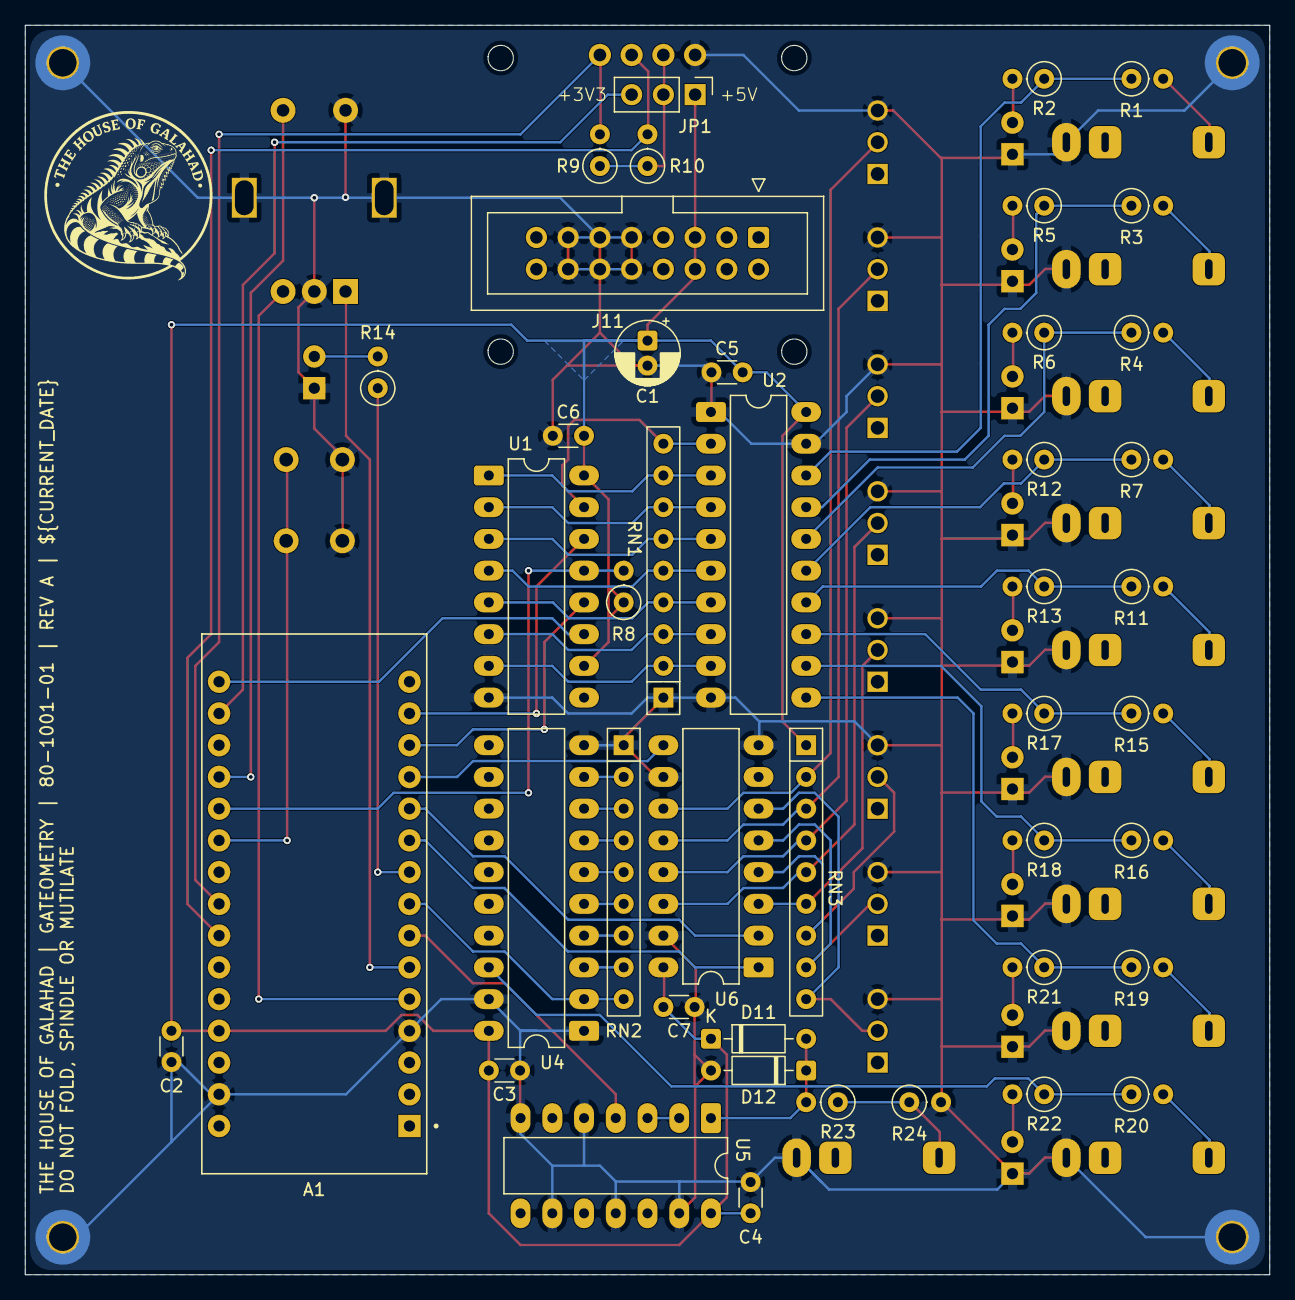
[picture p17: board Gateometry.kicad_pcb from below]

Board: 2 copper layers, 99.6 x 100.0 mm, 79 parts (44 on the bottom side), 74 nets.

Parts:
A1: Arduino_Nano_v3.x; MODULE_ARDUINO_NANO
C1: 47µ; CP_Radial_D5.0mm_P2.00mm
C2, C3, C4, C5, C6, C7: 100n; C_Disc_D3.0mm_W1.6mm_P2.50mm
D1: GATE1 LED; LED_D5.0mm_FlatTop
D2: GATE2 LED; LED_D5.0mm_FlatTop
D3: GATE3 LED; LED_D5.0mm_FlatTop
D4: GATE4 LED; LED_D5.0mm_FlatTop
D5: GATE5 LED; LED_D5.0mm_FlatTop
D6: CLOCK LED; LED_D5.0mm_FlatTop
D7: GATE6 LED; LED_D5.0mm_FlatTop
D8: GATE7 LED; LED_D5.0mm_FlatTop
D9: GATE8 LED; LED_D5.0mm_FlatTop
D10: CLOCK OUT LED; LED_D5.0mm_FlatTop
D11, D12: BAT85; D_DO-35_SOD27_P7.62mm_Horizontal
ENC1: ROTARY ENCODER; Rotary Encoder
H1, H2, H3, H4: MountingHole_Pad; MountingHole_2.2mm_M2_Pad_TopBottom
J1: GATE1; Jack_3.5mm_QingPu_WQP-PJ398SM_Vertical
J2: GATE2; Jack_3.5mm_QingPu_WQP-PJ398SM_Vertical
J3: GATE3; Jack_3.5mm_QingPu_WQP-PJ398SM_Vertical
J4: GATE4; Jack_3.5mm_QingPu_WQP-PJ398SM_Vertical
J5: GATE5; Jack_3.5mm_QingPu_WQP-PJ398SM_Vertical
J6: GATE6; Jack_3.5mm_QingPu_WQP-PJ398SM_Vertical
J7: GATE7; Jack_3.5mm_QingPu_WQP-PJ398SM_Vertical
J8: GATE8; Jack_3.5mm_QingPu_WQP-PJ398SM_Vertical
J9: CLOCK OUT; Jack_3.5mm_QingPu_WQP-PJ398SM_Vertical
J10: CLOCK IN; Jack_3.5mm_QingPu_WQP-PJ398SM_Vertical
J11: POWER; IDC-Header_2x08_P2.54mm_Vertical
JP1: OLED POWER; PinHeader_1x03_P2.54mm_Vertical
R1, R3, R4, R7, R11, R15, R16, R19, R20: 1k; R_Axial_DIN0207_L6.3mm_D2.5mm_P2.54mm_Vertical
R2, R5, R6, R12, R13, R17, R18, R21, R22: 4k7; R_Axial_DIN0207_L6.3mm_D2.5mm_P2.54mm_Vertical
R8, R9, R10: 10k; R_Axial_DIN0207_L6.3mm_D2.5mm_P2.54mm_Vertical
R14: 2k2; R_Axial_DIN0207_L6.3mm_D2.5mm_P2.54mm_Vertical
R23: 22k; R_Axial_DIN0207_L6.3mm_D2.5mm_P2.54mm_Vertical
R24: 100k; R_Axial_DIN0207_L6.3mm_D2.5mm_P2.54mm_Vertical
RN1, RN2: 100k; R_Array_SIP9
RN3: 10k; R_Array_SIP9
SW1: RUN/STOP; SW_PUSH_6mm_H8mm
SW2: MUTE1; 2MS1T1B1M2QES
SW3: MUTE2; 2MS1T1B1M2QES
SW4: MUTE3; 2MS1T1B1M2QES
SW5: MUTE4; 2MS1T1B1M2QES
SW6: MUTE5; 2MS1T1B1M2QES
SW7: MUTE6; 2MS1T1B1M2QES
SW8: MUTE7; 2MS1T1B1M2QES
SW9: MUTE8; 2MS1T1B1M2QES
U1: 74HC595; DIP-16_W7.62mm_LongPads
U2, U4: 74HCT541; DIP-20_W7.62mm_LongPads
U3: 0.96 Inch OLED I2C Display Module
U5: 74HCT14; DIP-14_W7.62mm_LongPads
U6: 74HC165; DIP-16_W7.62mm_LongPads

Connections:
+3V3: A1.17 (3V3), JP1.3 (B)
+5V: A1.27 (+5V), C1.1, C2.1, C3.1, C4.1, C5.1, C6.1, C7.1, D11.1 (K), J11.5 (+12V), J11.6, JP1.1 (A), R8.1, RN3.1 (common), U1.10 (~SRCLR), U1.16 (VCC), U2.20 (VCC), U4.20 (VCC), U5.14 (VCC), U6.16 (VCC)
CLOCK IN: A1.7 (D4), U5.4
CLOCK OUT: A1.8 (D5), RN2.9 (R8), U4.2 (A0)
GND: A1.4 (GND), A1.29 (GND), C1.2, C2.2, C3.2, C4.2, C5.2, C6.2, C7.2, D1.1 (K), D2.1 (K), D3.1 (K), D4.1 (K), D5.1 (K), D6.1 (K), D7.1 (K), D8.1 (K), D9.1 (K), D10.1 (K), D12.2 (A), ENC1.C, ENC1.MP, ENC1.S2, H1.1 (1_1), H2.1 (1_1), H3.1 (1_1), H4.1 (1_1), J1.S (SHEILD), J2.S (SHEILD), J3.S (SHEILD), J4.S (SHEILD), J5.S (SHEILD), J6.S (SHEILD), J7.S (SHEILD), J8.S (SHEILD), J9.S (SHEILD), J10.S (SHEILD), J11.9 (GND), J11.10 (GND), J11.11 (GND), J11.12 (GND), J11.13 (-12), J11.14 (-12V), R24.2, RN1.1 (common), RN2.1 (common), SW1.2 (B), SW2.3 (C), SW3.3 (C), SW4.3 (C), SW5.3 (C), SW6.3 (C), SW7.3 (C), SW8.3 (C), SW9.3 (C), U1.8 (GND), U2.1 (G1), U2.10 (GND), U2.19 (G2), U3.1 (GND), U4.1 (G1), U4.10 (GND), U4.19 (G2), U5.5, U5.7 (GND), U5.9, U5.11, U5.13, U6.8 (GND), U6.10 (DS), U6.15 (~CE)
unnamed: A1.19 (A0), ENC1.S1
unnamed: A1.20 (A1), R8.2, U1.13 (~OE)
unnamed: A1.21 (A2), SW1.1 (A)
unnamed: A1.23 (A4), R9.2, U3.4 (SDA)
unnamed: A1.24 (A5), R10.2, U3.3 (SCL)
unnamed: A1.5 (D2), ENC1.B
unnamed: A1.6 (D3), ENC1.A
unnamed: A1.9 (D6), R14.1
unnamed: A1.10 (D7), U6.1 (~PL)
unnamed: A1.11 (D8), U6.2 (CP)
unnamed: A1.12 (D9), U6.9 (Q7)
unnamed: A1.13 (D10), U1.12 (RCLK)
unnamed: A1.14 (D11), U1.14 (SER)
unnamed: A1.16 (D13), U1.11 (SRCLK)
unnamed: D1.2 (A), R2.2
unnamed: D2.2 (A), R5.2
unnamed: D3.2 (A), R6.2
unnamed: D4.2 (A), R12.2
unnamed: D5.2 (A), R13.2
unnamed: D6.2 (A), R14.2
unnamed: D7.2 (A), R17.2
unnamed: D8.2 (A), R18.2
unnamed: D9.2 (A), R21.2
unnamed: D10.2 (A), R22.2
unnamed: D11.2 (A), D12.1 (K), R23.2, U5.1
unnamed: J1.T (SIG), R1.2
unnamed: J2.T (SIG), R3.2
unnamed: J3.T (SIG), R4.2
unnamed: J4.T (SIG), R7.2
unnamed: J5.T (SIG), R11.2
unnamed: J6.T (SIG), R15.2
unnamed: J7.T (SIG), R16.2
unnamed: J8.T (SIG), R19.2
unnamed: J9.T (SIG), R20.2
unnamed: J10.T (SIG), R23.1, R24.1
unnamed: JP1.2 (C), R9.1, R10.1, U3.2 (VCC)
unnamed: RN1.2 (R1), U1.7 (QH), U2.9 (A7)
unnamed: RN1.3 (R2), U1.6 (QG), U2.8 (A6)
unnamed: RN1.4 (R3), U1.5 (QF), U2.7 (A5)
unnamed: RN1.5 (R4), U1.4 (QE), U2.6 (A4)
unnamed: RN1.6 (R5), U1.3 (QD), U2.5 (A3)
unnamed: RN1.7 (R6), U1.2 (QC), U2.4 (A2)
unnamed: RN1.8 (R7), U1.1 (QB), U2.3 (A1)
unnamed: RN1.9 (R8), U1.15 (QA), U2.2 (A0)
unnamed: RN2.2 (R1), U4.9 (A7)
unnamed: RN2.3 (R2), U4.8 (A6)
unnamed: RN2.4 (R3), U4.7 (A5)
unnamed: RN2.5 (R4), U4.6 (A4)
unnamed: RN2.6 (R5), U4.5 (A3)
unnamed: RN2.7 (R6), U4.4 (A2)
unnamed: RN2.8 (R7), U4.3 (A1)
unnamed: RN3.2 (R1), SW2.2 (B), U6.11 (D0)
unnamed: RN3.3 (R2), SW3.2 (B), U6.12 (D1)
unnamed: RN3.4 (R3), SW4.2 (B), U6.13 (D2)
unnamed: RN3.5 (R4), SW5.2 (B), U6.14 (D3)
unnamed: RN3.6 (R5), SW6.2 (B), U6.3 (D4)
unnamed: RN3.7 (R6), SW7.2 (B), U6.4 (D5)
unnamed: RN3.8 (R7), SW8.2 (B), U6.5 (D6)
unnamed: RN3.9 (R8), SW9.2 (B), U6.6 (D7)
unnamed: R1.1, R2.1, U2.18 (Y0)
unnamed: R3.1, R5.1, U2.17 (Y1)
unnamed: R4.1, R6.1, U2.16 (Y2)
unnamed: R7.1, R12.1, U2.15 (Y3)
unnamed: R11.1, R13.1, U2.14 (Y4)
unnamed: R15.1, R17.1, U2.13 (Y5)
unnamed: R16.1, R18.1, U2.12 (Y6)
unnamed: R19.1, R21.1, U2.11 (Y7)
unnamed: R20.1, R22.1, U4.18 (Y0)
unnamed: U5.2, U5.3

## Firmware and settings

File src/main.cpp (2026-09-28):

#include <Arduino.h>
#include <Adafruit_GFX.h>
#include <Adafruit_SSD1306.h>
#include <SPI.h>
#include <Wire.h>
#include <avr/interrupt.h>
#include <avr/pgmspace.h>
#include <util/atomic.h>
#include "RhythmEngine.h"

#if !defined(__AVR_ATmega328P__) || F_CPU != 16000000UL
#error "Gateometry requires a classic 16 MHz ATmega328P Nano."
#endif

namespace {
// Direct-port code below also depends on these assignments; see README.md.
constexpr uint8_t EncoderA = 2, EncoderB = 3, ClockIn = 4;
constexpr uint8_t ClockOut = 5, ClockLed = 6;
constexpr uint8_t SwitchLoad = 7, SwitchClock = 8, SwitchData = 9;
constexpr uint8_t GateLatch = 10; // 595 data = D11, clock = D13 (hardware SPI)
constexpr uint8_t EncoderButton = A0, GateEnable = A1, RunButton = A2;
constexpr uint8_t OledAddress = 0x3C;
constexpr int8_t EncoderDirection = 1; // Use -1 if rotation feels backwards.
constexpr int8_t EncoderTransitions = 4; // Some encoders need 2 per detent.
constexpr uint16_t DebounceMs = 20, LongPressMs = 600;

Adafruit_SSD1306 display(128, 64, &Wire, -1, 400000UL, 400000UL);
ritmo::Engine engine;
ritmo::Settings settings[ritmo::ChannelCount];
volatile int8_t encoderMovement = 0;
uint8_t encoderPrevious = 0;
uint8_t lastGates = 0xFF;
bool displayReady = false;

// Only call in an ISR or ATOMIC_BLOCK. SPI is reserved exclusively for the 595.
void flushOutputs() {
    const uint8_t gates = engine.gates;
    if (gates != lastGates) {
        PORTB &= ~_BV(PB2); // D10 latch low
        SPDR = gates;
        while (!(SPSR & _BV(SPIF))) {}
        (void)SPDR;
        PORTB |= _BV(PB2);
        lastGates = gates;
    }
    if (engine.clockHigh) PORTD |= _BV(PD5) | _BV(PD6);
    else PORTD &= ~(_BV(PD5) | _BV(PD6));
}

const int8_t EncoderTable[16] PROGMEM = {
    0, -1, 1, 0, 1, 0, 0, -1, -1, 0, 0, 1, 0, 1, -1, 0
};

void encoderChanged() {
    const uint8_t state = (PIND >> 2) & 3;
    const int8_t delta = int8_t(pgm_read_byte(&EncoderTable[(encoderPrevious << 2) | state]));
    encoderPrevious = state;
    const int16_t next = int16_t(encoderMovement) + delta;
    if (next >= -120 && next <= 120) encoderMovement = next;
}

struct Button {
    uint8_t pin;
    bool candidate = false, down = false;
    uint32_t changed = 0;
    explicit Button(uint8_t p) : pin(p) {}
    // 1 = pressed, -1 = released, 0 = no debounced transition.
    int8_t poll(uint32_t now) {
        const bool sample = digitalRead(pin) == LOW;
        if (sample != candidate) { candidate = sample; changed = now; }
        if (candidate != down && uint32_t(now - changed) >= DebounceMs) {
            down = candidate;
            return down ? 1 : -1;
        }
        return 0;
    }
};
Button runButton(RunButton), encoderButton(EncoderButton);

enum class Page : uint8_t { Overview, Global, Channel };
Page page = Page::Overview;
uint8_t selection = 0; // 0 = global header, 1..8 = channels
uint8_t field = 0;
uint16_t bpm = 120;
uint8_t rateIndex = 2;
bool externalClock = false;
uint32_t encoderPressedAt = 0;
bool longPressHandled = false;

int16_t bounded(int16_t value, int16_t low, int16_t high) {
    return value < low ? low : (value > high ? high : value);
}

void configureChannel(uint8_t index) {
    const uint32_t bits = ritmo::pattern(settings[index]);
    ATOMIC_BLOCK(ATOMIC_RESTORESTATE) {
        engine.configure(index, settings[index], bits);
        flushOutputs();
    }
}

void turnEncoder(int8_t delta) {
    if (page == Page::Overview) {
        int16_t next = (int16_t(selection) + delta) % 9;
        if (next < 0) next += 9;
        selection = next;
    } else if (page == Page::Global) {
        if (field == 0) {
            const bool source = delta > 0;
            if (source != externalClock) {
                externalClock = source;
                ATOMIC_BLOCK(ATOMIC_RESTORESTATE) {
                    engine.setSource(source);
                    // Match an already-high external input without inventing a step.
                    if (source) engine.clockHigh = (PIND & _BV(PD4)) != 0;
                    flushOutputs();
                }
            }
        } else if (field == 1) {
            bpm = bounded(int16_t(bpm) + delta, 20, 300);
            ATOMIC_BLOCK(ATOMIC_RESTORESTATE) { engine.bpm = bpm; }
        } else {
            rateIndex = bounded(int16_t(rateIndex) + delta, 0, 3);
            ATOMIC_BLOCK(ATOMIC_RESTORESTATE) { engine.stepsPerBeat = 1 << rateIndex; }
        }
    } else {
        const uint8_t ch = selection - 1;
        ritmo::Settings &s = settings[ch];
        switch (field) {
        case 0:
            s.steps = bounded(int16_t(s.steps) + delta, 1, ritmo::MaxSteps);
            if (s.hits > s.steps) s.hits = s.steps;
            s.rotation = bounded(s.rotation, 1 - int16_t(s.steps), s.steps - 1);
            break;
        case 1: s.hits = bounded(int16_t(s.hits) + delta, 0, s.steps); break;
        case 2: s.rotation = bounded(int16_t(s.rotation) + delta, 1 - int16_t(s.steps), s.steps - 1); break;
        case 3: s.duty = bounded(int16_t(s.duty) + delta, 1, 99); break;
        }
        configureChannel(ch);
    }
}

void clickEncoder() {
    if (page == Page::Overview) {
        page = selection ? Page::Channel : Page::Global;
        field = 0;
    } else {
        field = (field + 1) % (page == Page::Global ? 3 : 4);
    }
}

uint8_t readSwitches() {
    // QH holds H before the first clock: H->bit7, ..., A->bit0.
    uint8_t bits = 0;
    digitalWrite(SwitchClock, LOW);
    digitalWrite(SwitchLoad, LOW);
    delayMicroseconds(1);
    digitalWrite(SwitchLoad, HIGH);
    for (uint8_t i = 0; i < 8; ++i) {
        bits = (bits << 1) | (digitalRead(SwitchData) == HIGH);
        digitalWrite(SwitchClock, HIGH);
        digitalWrite(SwitchClock, LOW);
    }
    return bits; // Pull-up = enabled; switch closed to GND = muted.
}

void pollSwitches(uint32_t now) {
    static uint32_t lastPoll = 0;
    static uint8_t stable = 0, candidate = 0;
    static uint16_t changed[8] = {};
    if (uint32_t(now - lastPoll) < 5) return;
    lastPoll = now;
    const uint8_t sample = readSwitches();
    for (uint8_t i = 0; i < 8; ++i) {
        const uint8_t bit = uint8_t(1) << i;
        if ((sample ^ candidate) & bit) {
            candidate ^= bit;
            changed[i] = uint16_t(now);
        }
        if (((stable ^ candidate) & bit) && uint16_t(uint16_t(now) - changed[i]) >= DebounceMs)
            stable ^= bit;
    }
    ATOMIC_BLOCK(ATOMIC_RESTORESTATE) {
        engine.setEnabled(stable);
        flushOutputs();
    }
}

void pollControls(uint32_t now) {
    if (runButton.poll(now) == 1) {
        ATOMIC_BLOCK(ATOMIC_RESTORESTATE) {
            engine.setRunning(!engine.running);
            flushOutputs();
        }
    }
    const int8_t event = encoderButton.poll(now);
    if (event == 1) { encoderPressedAt = now; longPressHandled = false; }
    if (encoderButton.down && !longPressHandled && uint32_t(now - encoderPressedAt) >= LongPressMs) {
        page = Page::Overview;
        longPressHandled = true;
    }
    if (event == -1 && !longPressHandled) clickEncoder();
    int8_t movement;
    ATOMIC_BLOCK(ATOMIC_RESTORESTATE) { movement = encoderMovement; encoderMovement = 0; }
    static int16_t remainder = 0;
    remainder += movement * EncoderDirection;
    const int8_t detents = remainder / EncoderTransitions;
    remainder %= EncoderTransitions;
    if (detents) turnEncoder(detents);
    pollSwitches(now);
}

struct Snapshot {
    uint8_t current[8];
    uint8_t gates, enabled;
    uint16_t period;
    bool running, locked;
};

// A quarter sine wave in flash avoids floating point and coordinate RAM tables.
const uint8_t SineQuarter[17] PROGMEM = {
    0, 12, 25, 37, 49, 60, 71, 81, 90, 98, 106, 112, 117, 122, 125, 126, 127
};
int16_t sine(uint8_t angle) {
    angle &= 63;
    const uint8_t quadrant = angle >> 4;
    const uint8_t offset = angle & 15;
    const int16_t value = pgm_read_byte(&SineQuarter[(quadrant & 1) ? 16 - offset : offset]);
    return quadrant >= 2 ? -value : value;
}
void point(uint8_t slot, uint8_t steps, int8_t radius, int16_t &x, int16_t &y) {
    const uint8_t angle = uint16_t(slot) * 64 / steps;
    x = sine(angle) * radius / 127;
    y = -sine(angle + 16) * radius / 127;
}

void necklace(uint8_t ch, int16_t cx, int16_t cy, int8_t radius, uint8_t current, bool large) {
    const ritmo::Settings &s = settings[ch];
    const uint32_t bits = ritmo::pattern(s);
    if (large) display.drawCircle(cx, cy, radius, SSD1306_WHITE);
    for (uint8_t slot = 0; slot < s.steps; ++slot) {
        int16_t x, y;
        point(slot, s.steps, radius, x, y);
        if (bits & (uint32_t(1) << slot)) display.fillCircle(cx + x, cy + y, large ? 2 : 1, SSD1306_WHITE);
        else if (large) display.drawCircle(cx + x, cy + y, 1, SSD1306_WHITE);
        else display.drawPixel(cx + x, cy + y, SSD1306_WHITE);
    }
    if (current != ritmo::NoSlot) {
        int16_t x, y, x2, y2;
        point(current, s.steps, radius + (large ? 4 : 2), x, y);
        point(current, s.steps, large ? 5 : 3, x2, y2);
        display.drawLine(cx + x2, cy + y2, cx + x, cy + y, SSD1306_WHITE);
    }
}

void drawHeader(const Snapshot &s) {
    const bool selected = page == Page::Overview && selection == 0;
    if (selected) display.fillRect(0, 0, 128, 8, SSD1306_WHITE);
    display.setTextColor(selected ? SSD1306_BLACK : SSD1306_WHITE);
    display.setCursor(0, 0);
    display.print(s.running ? F("RUN ") : F("STOP "));
    if (externalClock) {
        display.print(F("EXT "));
        if (s.locked) { display.print(s.period); display.print(F("ms")); }
        else display.print(F("WAIT"));
    } else {
        display.print(F("INT "));
        display.print(bpm);
        display.print(F(" BPM"));
    }
    display.setTextColor(SSD1306_WHITE);
}

void drawField(uint8_t index, uint8_t x, uint8_t y, const __FlashStringHelper *label, int16_t value) {
    display.setCursor(x, y);
    display.print(field == index ? '>' : ' ');
    display.print(label);
    display.print(value);
}

void render() {
    Snapshot s;
    ATOMIC_BLOCK(ATOMIC_RESTORESTATE) {
        for (uint8_t i = 0; i < 8; ++i) s.current[i] = engine.channels[i].current;
        s.gates = engine.gates;
        s.enabled = engine.enabled;
        s.running = engine.running;
        s.locked = engine.externalSeen;
        s.period = engine.period;
    }
    display.clearDisplay();
    drawHeader(s);
    if (page == Page::Overview) {
        for (uint8_t i = 0; i < 8; ++i) {
            const uint8_t x = (i % 4) * 32, y = 9 + (i / 4) * 27;
            if (selection == i + 1) display.drawRect(x, y, 32, 27, SSD1306_WHITE);
            display.setCursor(x + 2, y + 2);
            display.print(i + 1);
            necklace(i, x + 17, y + 13, 9, s.current[i], false);
            if (!(s.enabled & (1 << i))) {
                display.drawLine(x + 9, y + 21, x + 25, y + 5, SSD1306_WHITE);
            }
            if (s.gates & (1 << i)) display.fillRect(x + 2, y + 21, 3, 3, SSD1306_WHITE);
        }
    } else if (page == Page::Global) {
        display.setCursor(0, 14);
        display.print(field == 0 ? F(">Clock: ") : F(" Clock: "));
        display.print(externalClock ? F("External") : F("Internal"));
        drawField(1, 0, 27, F("BPM: "), bpm);
        drawField(2, 0, 40, F("Steps/beat: "), 1 << rateIndex);
        display.setCursor(0, 56);
        display.print(F("Click:next Hold:back"));
    } else {
        const uint8_t ch = selection - 1;
        necklace(ch, 29, 37, 20, s.current[ch], true);
        display.setCursor(18, 34);
        display.print(F("CH")); display.print(ch + 1);
        if (!(s.enabled & (1 << ch))) {
            display.setCursor(18, 43); display.print(F("MUT"));
        }
        drawField(0, 62, 13, F("N:"), settings[ch].steps);
        drawField(1, 62, 24, F("K:"), settings[ch].hits);
        drawField(2, 62, 35, F("R:"), settings[ch].rotation);
        drawField(3, 62, 46, F("D:"), settings[ch].duty);
        display.print('%');
        display.setCursor(62, 57); display.print(F("Hold:back"));
    }
    display.display(); // Interrupts remain enabled throughout this I2C transfer.
    if (Wire.getWireTimeoutFlag()) {
        Wire.clearWireTimeoutFlag();
        displayReady = false; // Keep sequencing if the display bus fails.
    }
}
} // namespace

ISR(TIMER1_COMPA_vect) {
    engine.tick();
    flushOutputs();
}

ISR(PCINT2_vect) {
    engine.externalEdge((PIND & _BV(PD4)) != 0);
    flushOutputs();
}

void setup() {
    // External 10k OE pull-up keeps output buffers disabled during reset/boot.
    digitalWrite(GateEnable, HIGH);
    pinMode(GateEnable, OUTPUT);
    pinMode(GateLatch, OUTPUT);
    pinMode(ClockOut, OUTPUT);
    pinMode(ClockLed, OUTPUT);
    pinMode(ClockIn, INPUT); // External conditioner must drive a defined level.
    pinMode(EncoderA, INPUT_PULLUP);
    pinMode(EncoderB, INPUT_PULLUP);
    pinMode(EncoderButton, INPUT_PULLUP);
    pinMode(RunButton, INPUT_PULLUP);
    pinMode(SwitchLoad, OUTPUT);
    digitalWrite(SwitchLoad, HIGH);
    pinMode(SwitchClock, OUTPUT);
    pinMode(SwitchData, INPUT);
    SPI.begin();
    SPI.beginTransaction(SPISettings(8000000, MSBFIRST, SPI_MODE0));
    // No other SPI device is used: the interrupt-driven 595 owns this bus.
    engine.enabled = readSwitches();
    for (uint8_t i = 0; i < 8; ++i) configureChannel(i);
    ATOMIC_BLOCK(ATOMIC_RESTORESTATE) { flushOutputs(); }
    digitalWrite(GateEnable, LOW);

    Wire.begin();
    Wire.setWireTimeout(3000, true);
    Wire.beginTransmission(OledAddress);
    const bool oledPresent = Wire.endTransmission() == 0;
    displayReady = oledPresent && display.begin(SSD1306_SWITCHCAPVCC, OledAddress, true, false);
    if (displayReady) {
        display.setTextSize(1);
        display.setTextWrap(false);
        display.setTextColor(SSD1306_WHITE);
    }

    encoderPrevious = (PIND >> 2) & 3;
    attachInterrupt(digitalPinToInterrupt(EncoderA), encoderChanged, CHANGE);
    attachInterrupt(digitalPinToInterrupt(EncoderB), encoderChanged, CHANGE);
    ATOMIC_BLOCK(ATOMIC_RESTORESTATE) {
        PCMSK2 = _BV(PCINT20); // D4 pin-change interrupt; D2/D3 use INT0/INT1.
        PCIFR = _BV(PCIF2);
        PCICR |= _BV(PCIE2);
        TCCR1A = 0;
        TCCR1B = 0;
        TCNT1 = 0;
        OCR1A = F_CPU / 64 / 1000 - 1;
        TIFR1 = _BV(OCF1A);
        TCCR1B = _BV(WGM12) | _BV(CS11) | _BV(CS10);
        TIMSK1 = _BV(OCIE1A);
    }
}

void loop() {
    const uint32_t now = millis();
    pollControls(now);
    static uint32_t lastFrame = 0;
    if (displayReady && uint32_t(now - lastFrame) >= 67) {
        lastFrame = now;
        render(); // ~15 fps; clock and gates continue in interrupts.
    }
}

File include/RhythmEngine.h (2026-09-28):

#pragma once

#include <stdint.h>

namespace ritmo {
constexpr uint8_t ChannelCount = 8;
constexpr uint8_t MaxSteps = 32;
constexpr uint8_t NoSlot = 255;

struct Settings {
    uint8_t steps = 16;
    uint8_t hits = 4;
    int8_t rotation = 0;
    uint8_t duty = 50;
};

// Evenly spaced Euclidean onsets, anchored on slot zero before rotation.
// Positive rotation moves hits clockwise/later; no arrays or recursion needed.
inline uint32_t pattern(const Settings &s) {
    uint32_t result = 0;
    for (uint8_t slot = 0; slot < s.steps; ++slot) {
        if ((uint16_t(slot) * s.hits) % s.steps < s.hits) {
            int16_t rotated = (int16_t(slot) + s.rotation) % s.steps;
            if (rotated < 0) rotated += s.steps;
            result |= uint32_t(1) << rotated;
        }
    }
    return result;
}

inline uint16_t gateLength(uint16_t period, uint8_t duty) {
    uint16_t length = uint32_t(period) * duty / 100;
    if (length == 0) length = 1;
    // A low interval between adjacent hits is essential for retriggering.
    if (length >= period) length = period - 1;
    return length;
}

// Called from interrupts; foreground access must be inside ATOMIC_BLOCK.
// Volatile fields ensure foreground snapshots see interrupt updates on AVR.
class Engine {
public:
    struct Channel {
        volatile uint32_t bits = 0;
        volatile uint16_t remaining = 0;
        volatile uint8_t steps = 16;
        volatile uint8_t duty = 50;
        volatile uint8_t next = 0;
        volatile uint8_t current = NoSlot;
    } channels[ChannelCount];

    volatile uint32_t now = 0;
    volatile uint32_t lastExternal = 0;
    volatile uint32_t phase = 0;
    volatile uint16_t bpm = 120;
    volatile uint16_t period = 125;
    volatile uint16_t clockRemaining = 0;
    volatile uint8_t stepsPerBeat = 4;
    volatile uint8_t gates = 0;
    volatile uint8_t pending = 0;
    volatile uint8_t enabled = 0xFF;
    volatile bool running = false;
    volatile bool external = false;
    volatile bool externalSeen = false;
    volatile bool haveExternalEdge = false;
    volatile bool clockHigh = false;

    uint16_t internalPeriod() const {
        return 60000UL / (uint16_t(bpm) * stepsPerBeat);
    }

    void configure(uint8_t index, const Settings &s, uint32_t bits) {
        Channel &c = channels[index];
        c.bits = bits;
        c.steps = s.steps;
        c.duty = s.duty;
        c.remaining = 0;
        c.next = 0;
        c.current = NoSlot;
        gates &= ~(uint8_t(1) << index);
        pending &= ~(uint8_t(1) << index);
    }

    void setEnabled(uint8_t mask) {
        enabled = mask;
        gates &= mask;
        pending &= mask;
        for (uint8_t i = 0; i < ChannelCount; ++i)
            if (!(mask & (1 << i))) channels[i].remaining = 0;
    }

    void resetChannels() {
        gates = 0;
        pending = 0;
        for (uint8_t i = 0; i < ChannelCount; ++i) {
            channels[i].remaining = 0;
            channels[i].next = 0;
            channels[i].current = NoSlot;
        }
    }

    void setRunning(bool value) {
        running = value;
        resetChannels();
    }

    void setSource(bool value) {
        external = value;
        externalSeen = false;
        haveExternalEdge = false;
        phase = 0;
        clockHigh = false;
        clockRemaining = 0;
        period = internalPeriod();
        resetChannels();
    }

    void advance() {
        if (!running) return;
        for (uint8_t i = 0; i < ChannelCount; ++i) {
            Channel &c = channels[i];
            const uint8_t slot = c.next;
            c.current = slot;
            c.next = slot + 1 == c.steps ? 0 : slot + 1;
            const uint8_t bit = uint8_t(1) << i;
            if ((enabled & bit) && (c.bits & (uint32_t(1) << slot))) {
                c.remaining = gateLength(period, c.duty);
                if (gates & bit) {
                    // An unexpectedly early external edge must still retrigger.
                    // Force low now, then raise on the next timer tick.
                    gates &= ~bit;
                    pending |= bit;
                } else {
                    gates |= bit;
                    pending &= ~bit;
                }
            } else {
                c.remaining = 0;
                gates &= ~bit;
                pending &= ~bit;
            }
        }
    }

    // 1 kHz Timer1 service: OLED/Wire never runs in this context.
    void tick() {
        ++now;
        for (uint8_t i = 0; i < ChannelCount; ++i) {
            Channel &c = channels[i];
            const uint8_t bit = uint8_t(1) << i;
            if (pending & bit) {
                pending &= ~bit;
                gates |= bit;
            } else if (c.remaining && --c.remaining == 0) {
                gates &= ~bit;
            }
        }
        if (external) {
            uint32_t timeout = uint32_t(period) * 3;
            if (timeout < 1000) timeout = 1000;
            if (externalSeen && uint32_t(now - lastExternal) > timeout)
                externalSeen = false;
            return;
        }
        if (clockRemaining && --clockRemaining == 0) clockHigh = false;
        phase += uint16_t(bpm) * stepsPerBeat;
        if (phase >= 60000UL) {
            phase -= 60000UL;
            period = internalPeriod();
            clockHigh = true;
            clockRemaining = period / 2;
            advance();
        }
    }

    // Conditioned 0..5 V input. Every edge is copied; accepted rising edges
    // advance the sequencer. 20 ms minimum spacing limits steps to 50 Hz.
    void externalEdge(bool high) {
        if (!external) return;
        clockHigh = high;
        if (!high) return;
        const uint32_t elapsed = now - lastExternal;
        if (haveExternalEdge && elapsed < 20) return;
        period = haveExternalEdge && elapsed <= 10000 ? elapsed : internalPeriod();
        lastExternal = now;
        haveExternalEdge = true;
        externalSeen = true;
        advance();
    }
};
} // namespace ritmo

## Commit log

2026-09-28 Added KiCad projects for PCB and panel.
    [MiRitmo.kicad_pcb, MiRitmo.kicad_sch, MiRitmoPanel.kicad_pcb]
2026-09-28 project rename
    [Gateometry.kicad_pcb, Gateometry.kicad_sch, GateometryPanel.kicad_pcb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]
2026-09-28 initial final rev A schematic
    [Gateometry.kicad_pcb, Gateometry.kicad_sch, bom.csv]
2026-09-29 revsion A of pcb first iteration
    [Gateometry.kicad_pcb, Gateometry.kicad_sch]
2026-09-29 Add resources section to README
    Added resources section with PCB link and panel note.
2026-09-29 panel work
    [Gateometry.kicad_pcb, GateometryPanel.kicad_pcb]
2026-09-29 first revision A of board and panel
    [Gateometry.kicad_pcb, GateometryPanel.kicad_pcb]
2026-09-29 Enhance README with Gateometry PCB details
    Added a detailed description of the Gateometry PCB functionality and features.
